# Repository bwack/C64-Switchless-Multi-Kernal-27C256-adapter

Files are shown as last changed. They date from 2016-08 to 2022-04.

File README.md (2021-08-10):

README.txt

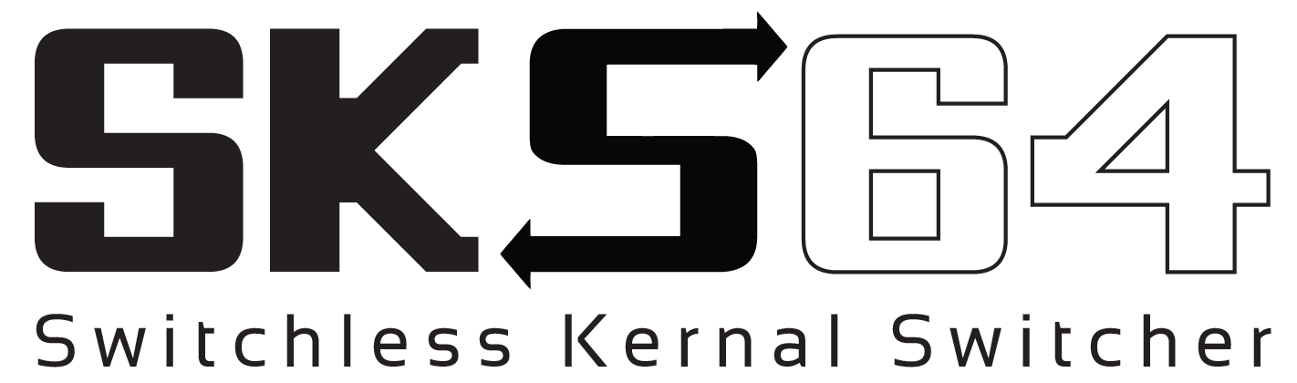
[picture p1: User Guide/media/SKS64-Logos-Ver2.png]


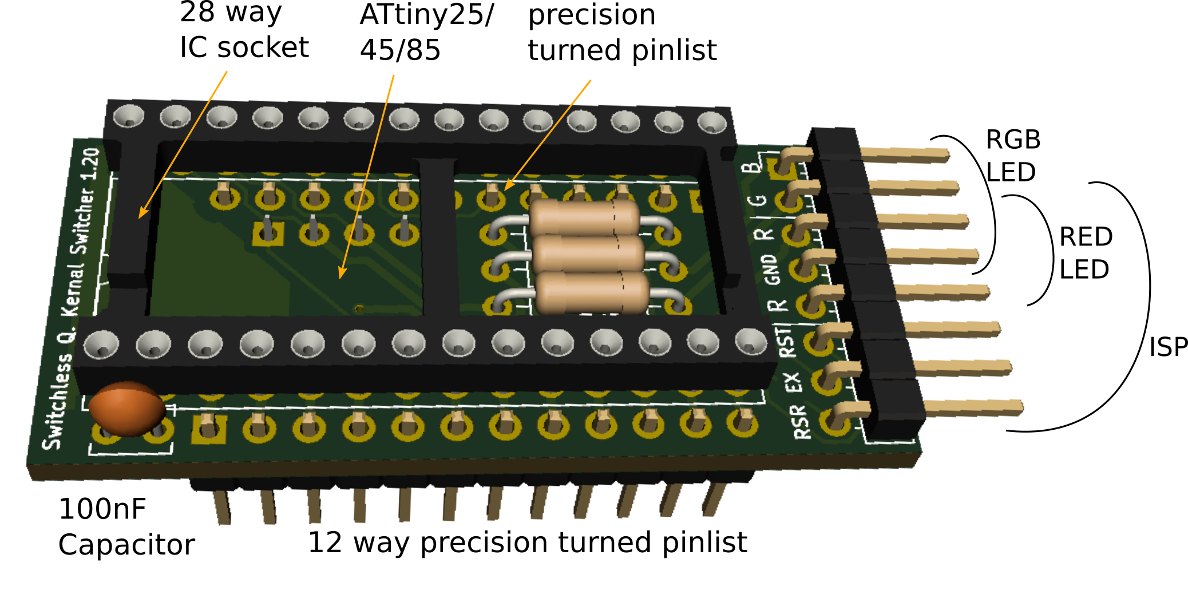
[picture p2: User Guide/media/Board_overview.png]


C64 Switchless Multi Kernel Switch
- 27C256/512 rom adapter for C64's and disk drives.

Designed by BWACK.
CERN OPEN HARDWARE LICENSE v1.2
http://www.ohwr.org/

The CAD files are available on GitHub:
https://github.com/bwack/C64-Switchless-Multi-Kernal-27C256-adapter

All text above must be included in any redistribution

# SKS64 Switchless Kernal Switcher

A kernal ROM adapter and switcher for C64, C64C, 1541, 1541C and 1541-II. The software is written in the Arduino IDE.

# How it works

## Switching Kernals

The current selected Kernal is indicated by a color using the RGB LED as power LED replacement. Holding the RESTORE key for several seconds until the LED flashes. You then release it and tap RESTORE until you get the kernal (color) you want. Wait a couple of seconds and the C64 reset with the new kernal selected.

1541 disk drives:
Now you can have the disk drive and the C64 switch at the same time! The reset pulse issued by the SKS64 now has prepended serial data indicating the bank number. When the SKS64 board in the disk drive is setup in 1541 mode, it will switch to the upper bank when the C64 is switched to bank1 (for example, JiffyDOS).

## Reset

Hold the RESTORE key for two seconds. The LED flashes. Release and wait two seconds for the reset.

## EXROM Reset (optional)

Hold the RESTORE key for five seconds. Some machine language programs change the way computer returns after a reset. In that case the only way to reset to basic is to turn the machine off. By controlling both RESET and EXROM it is possible to "cold start" the machine.

Note: EXROM reset is only available when the ATtiny's RESET pin is disabled (fuse bit #RSTDISBL). This can only be done with HV-programmers (like TL866).

# Hardware

There are two different PCBs for the SKS64.
- "longboard": works with C64 longboards and 1541/1541Late.
- "shortboard": works with C64C shortboards and 1541C/1541-II.

Note: The internals of C64/C64C and 1541/1541C are often mixed up, and you must look inside their cases to be sure which boards they have.

Gerbers and hex-files (for programming) are found under the release-tab above.

# Programming

Programming is done with ISP programmers or High-Voltage programmers. You can use an Arduino Uno as ISP. Please see the User Guide for more information.

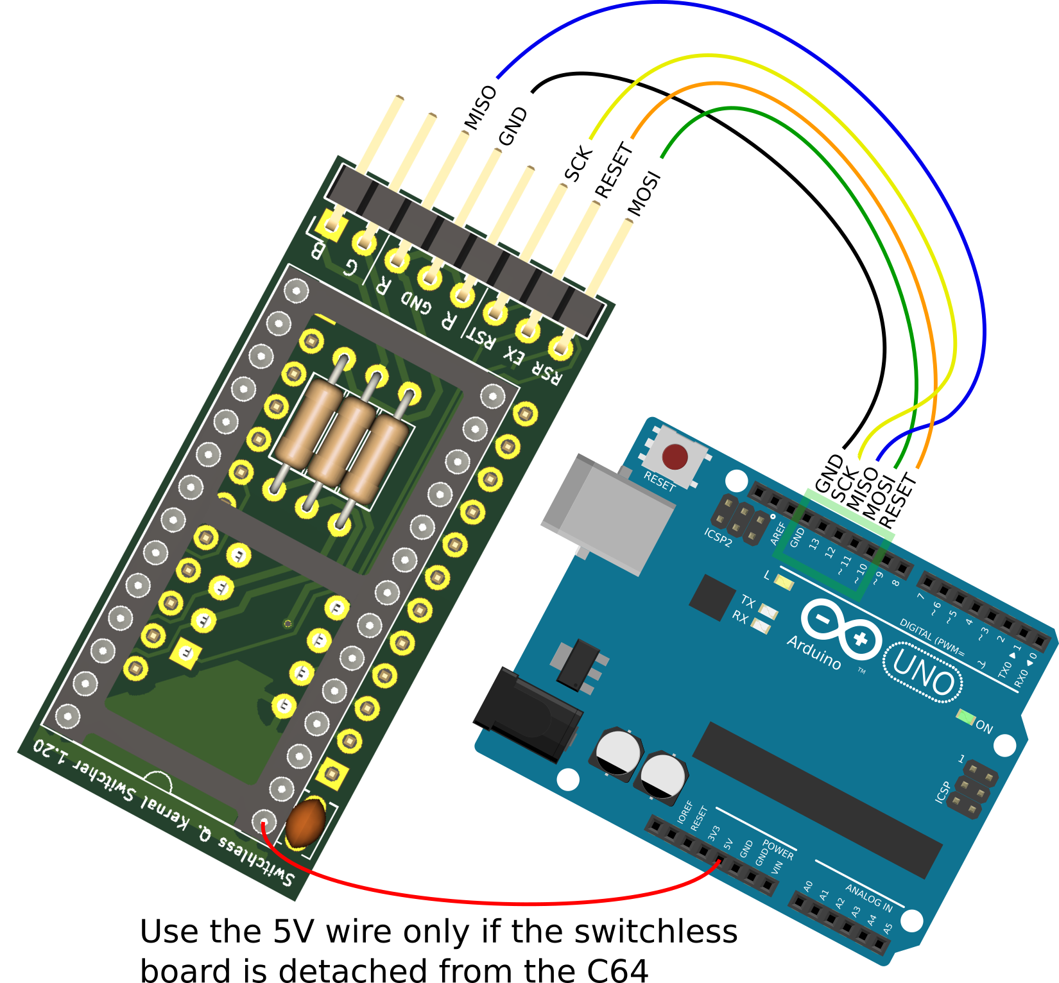
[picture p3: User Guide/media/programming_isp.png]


After programming, the board must enter setup mode. Please refer to the User Guide.

# ROM layout

ROM images are placed in 8k banks.
- C64 Longboard
  - place 4 kernals in a 32k image (27C256).
  - place 8 kernals in a 64k image (W27C512).
- C64 Shortboard
  - place BASIC + 3 kernals in a 32k image (27C256).
  - place BASIC + 7 kernals in a 64k image (W27C512).
- 1541
  - Place CBM DOS + JiffyDOS in a 16k image (27C128)

For 1541C/1541-II ROM images are placed in 16k banks.
- 1541C/1541-II
  - Place KERNAL+CBMDOS + KERNAL+JiffyDOS in a 32k image (27C256)

# Via locations
You can solder 1x1mm pin headers into motherboard vias to wire up RESTORE, RESET and EXROM.

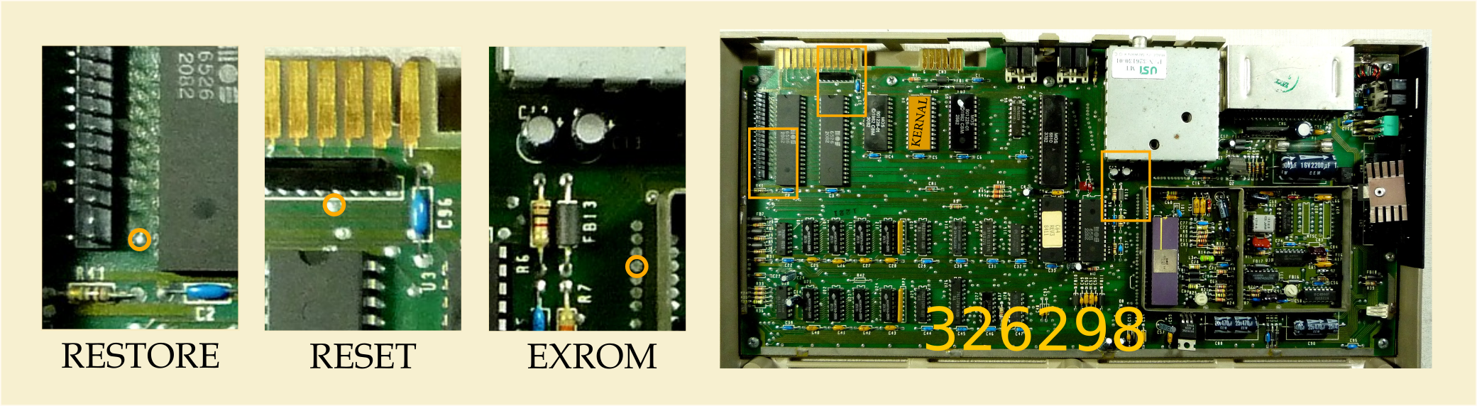
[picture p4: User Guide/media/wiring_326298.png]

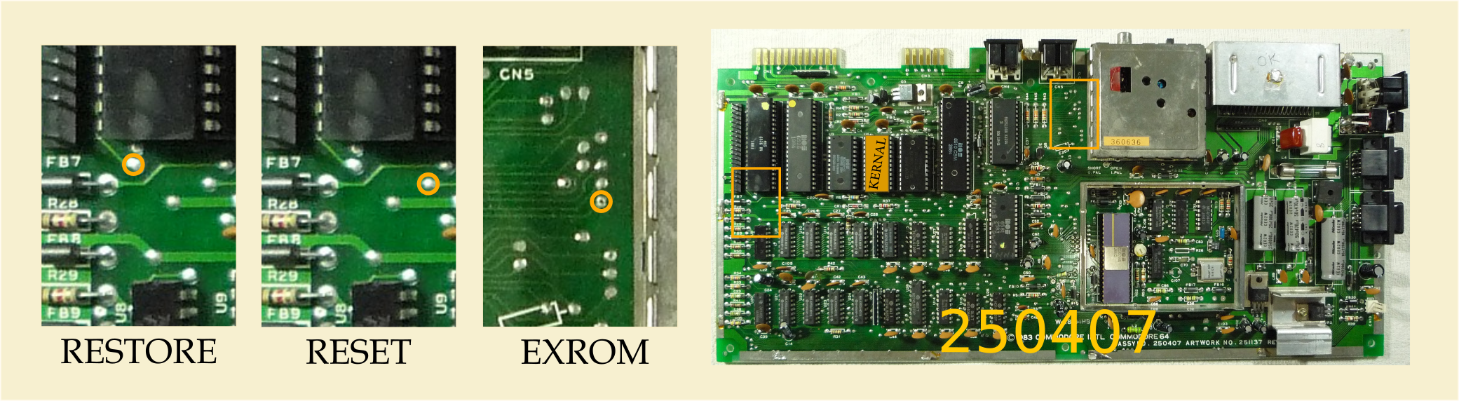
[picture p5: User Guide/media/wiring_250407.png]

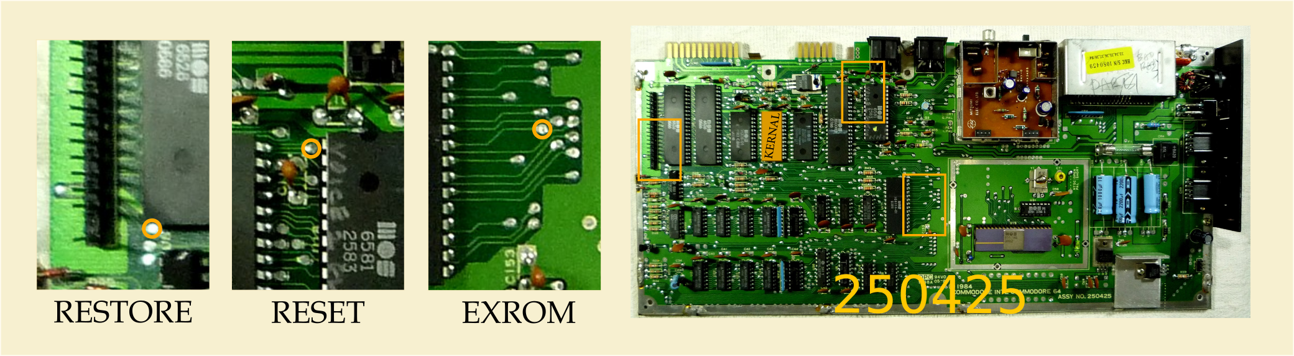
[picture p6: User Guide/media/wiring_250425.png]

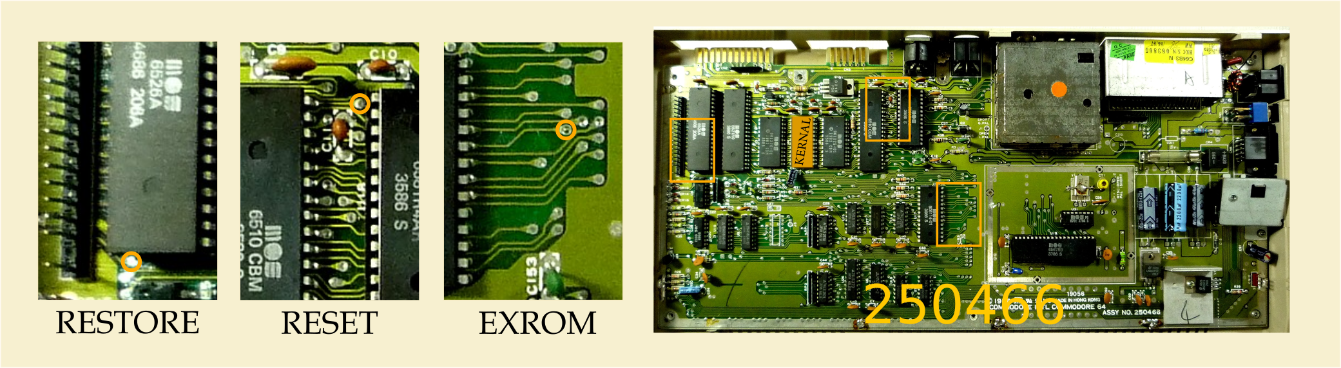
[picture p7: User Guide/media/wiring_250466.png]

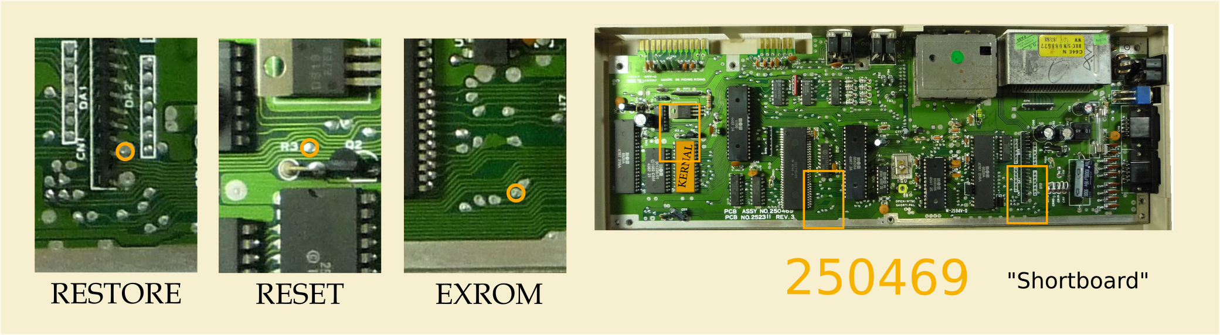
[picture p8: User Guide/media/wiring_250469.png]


# Acknowledgement

The Switchless Kernal Switcher for shortboards is based on Sven Petersen's [C64 Kernal Adaptor Switch shortboard](https://github.com/svenpetersen1965/C64-Kernal-Adaptor-Switch-short-board-). The old shortboard version is located at [DiscoHR's repository](https://github.com/discoHR/C64C-C128-multikernal-adapter). It is possible to use the original LED and cable assembly. This was an idea I found on [tebl's repository](https://github.com/tebl/C64-Kernal-Switcher).

# Project links
- lemon64:  http://www.lemon64.com/forum/viewtopic.php?p=747333
- playlist: https://www.youtube.com/watch?v=oGaI8yLwjh4&list=PLtQOf_JULmrQTB7486X5pXG1Aaxbl_RdE
- OSH Park: https://oshpark.com/profiles/bwack
- Github:   https://github.com/bwack/C64-Switchless-Multi-Kernal-27C256-adapter

# Change log
## longboard version
- Rev 1.21 (2019-07-23):
  - Support 27C512 and 8 banks
- Rev 1.20 (2019-07-14):
  - Eagle -> KiCad.
  - PIC12F629 -> ATTINY45/85. Note: Pinout is different! Don't mix up PIC12F with ATTINY!
  - Programming with Arduino IDE.
  - Programmers: ISP: USBasp or Arduino UNO as ISP. High-Voltage: TL866.
  - Use the original LED or a common cathode RGB LED.
  - User Guide rewritten for this revision.
- Rev 1.13 (2016-09-28):
  - Moved IC2 down to clear space for the socket in the c64.
  - Changes to the silk screen.
- Rev 1.12 (2016-09-18):
  - Increased pad and hole sizes.
  - Removed ground fill from top layer.
  - Added CERN OHL v1.2 License.
- Rev 1.11 (2016-09-10):
  - RGB Led header following RGB led pinout (Blue-Green-GND-Red).
  - Edited silkscreen.
- Rev 1.1  (2016-09-08):
  - sch+brd.
  - Swapped signals #RESTORE and RED_LED. GP3 is input only.

## shortboard version
- Rev 1.0 (2019-07-18)
  - Initial design
- Rev 1.1 (2021-08-10)
  - jumpers for 1541C/1541-II support

Note: The schematic revision follows the board revision number.

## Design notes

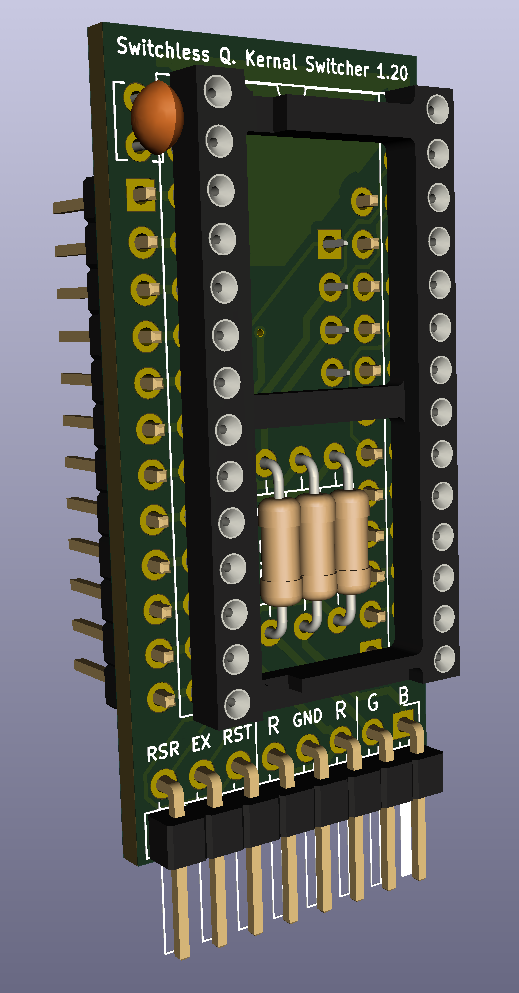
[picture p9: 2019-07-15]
KiCad_longboard/C64_Switchless_3D_front.png

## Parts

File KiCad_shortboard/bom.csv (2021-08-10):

Reference | Quantity | Value | Footprint | Datasheet
C1 | 1 | 100nF | Resistor_SMD:R_0805_2012Metric_Pad1.15x1.40mm_HandSolder | ~
J2 J1 | 2 | 01x14_precision_pinlist | Connector_PinHeader_2.54mm:PinHeader_1x14_P2.54mm_Vertical | ~
J3 | 1 | 27C256/512_28PDIP | Package_DIP:DIP-28_W15.24mm_Socket | ~
J4 | 1 | Wireconnections | Connector_PinHeader_2.54mm:PinHeader_1x08_P2.54mm_Horizontal | ~
R1 | 1 | 1k | Resistor_SMD:R_0805_2012Metric_Pad1.15x1.40mm_HandSolder | ~
R2 | 1 | 3k3 | Resistor_SMD:R_0805_2012Metric_Pad1.15x1.40mm_HandSolder | ~
R3 | 1 | 560 | Resistor_SMD:R_0805_2012Metric_Pad1.15x1.40mm_HandSolder | ~
U1 | 1 | ATtiny85-20PU | Package_DIP:DIP-8_W7.62mm_Socket | http://ww1.microchip.com/downloads/en/DeviceDoc/atmel-2586-avr-8-bit-microcontroller-attiny25-attiny45-attiny85_datasheet.pdf
U2 | 1 | 74LS08 | Note: NOT NEEDED with 1541C version! Package_SO:SOIC-14_3.9x8.7mm_P1.27mm | http://www.ti.com/lit/gpn/sn74LS08

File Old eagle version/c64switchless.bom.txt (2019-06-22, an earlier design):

Partlist exported from C:/Mine Dokumenter/eagle/projects/C64-SwitchlessMultiKernal/c64switchless.sch at 10.09.2016 17:06:57
(edited)

PCB Assembly variant: 

Qty Value            Device          Parts     
1   27C256 ROM       DIL28ROUND      IC1
2   Rounded pin list MA12-1ROUND     SV1, SV2  
1   RGB LED header   MA03-2          SV3       
1   1k               R-EU_0207/10    R1
1   3k3              R-EU_0207/10    R2
1   560R             R-EU_0207/10    R3
1   100n             C-EU025-024X044 C1        
1   PIC12F629P       PIC12F629P      IC2       

Eagle says, What ? :
- IC1:      27C256 ROM = socket for 28 pin IC.
- IC2:      Microcontroller PIC12F629P, 8 pin PDIP
- SV1, SV2: 2x12pin rounded pinlists on the bottom side
            These goes into the C64 socket, and into the
            adapter.
- SV3:      RGB LED assembly header.
            Standard 2x3 male header pinlist 2.56mm pitch
- R1,R2,R3: Resistors. Controls the brightness of the RGB LEDs.
- C1:       100nF ceramic capacitor, 2.56mm pitch

RGB LED assembly:
Qty    Value       
1      5mm RGB LED Common Cathode
300mm  4 wire rainbow IDC cable
1      2x3 IDC connector
80mm   heat shrink tubing 3.2mm/1.6mm 2:1 thin wall black

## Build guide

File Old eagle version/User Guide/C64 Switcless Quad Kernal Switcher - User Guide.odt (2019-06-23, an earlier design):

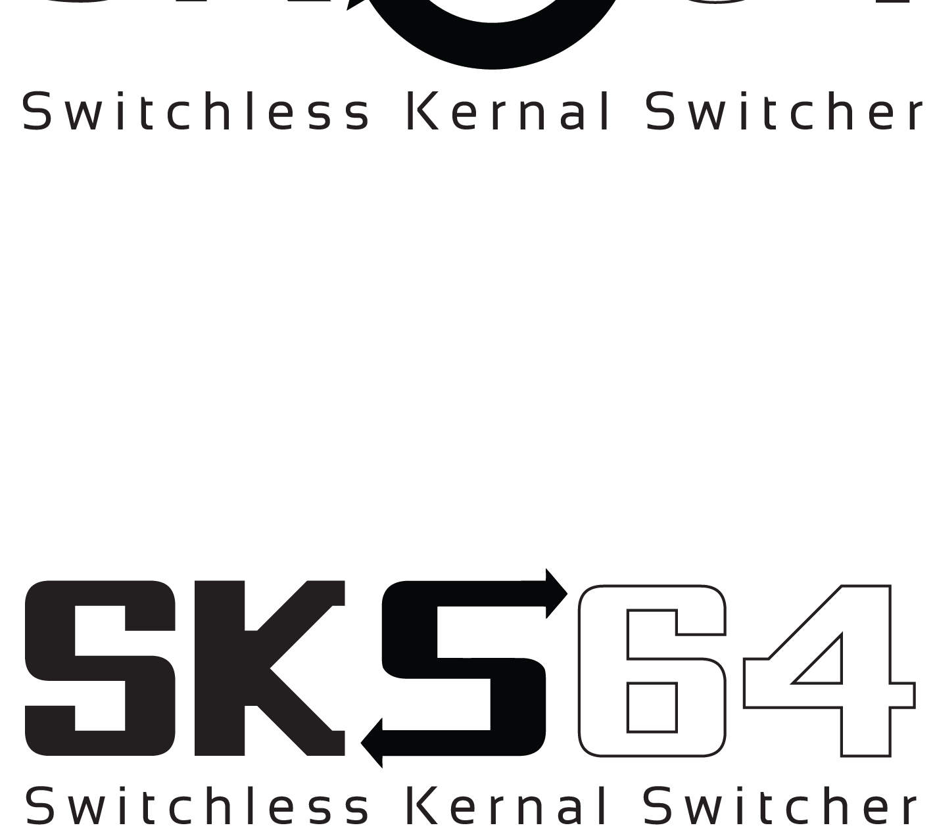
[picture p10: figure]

a Switchless Quad Kernal Switcher design for the C64 and C64C

User Guide

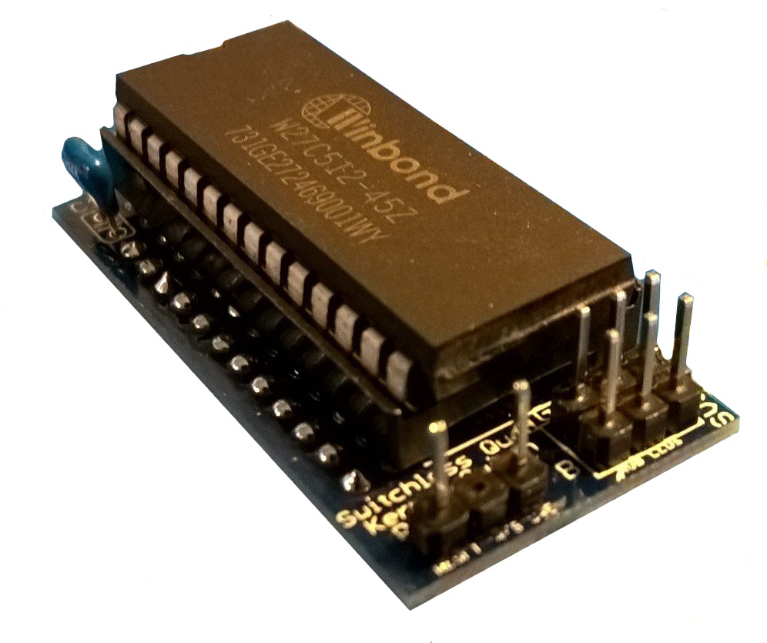
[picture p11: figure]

# Introduction

The Switchless Quad Kernal Switcher turns your C64 into a flying raspberry flavoured pumpkin that can boost the performance of your computer. It is high on itself and makes your C64 smoke out of the I/O ports. It is UL94 rated, so no flames though. Wear eye protection. Selected Kernal is indicated with a color power indicator. Maybe you just need a 24-28 adapter, the Switchless Quad Kernal Switcher is just what you need.

There is also a C64C version, for people who are fortunate to have 250469 PCB boards. Note that some C64C looking cases may have C64 motherboards ! You have to open it up to see.

The SKS64 can also be used as a 24 to 28 pin adapter. Only sockets and the ROM is required for the adapter.

# Board overview

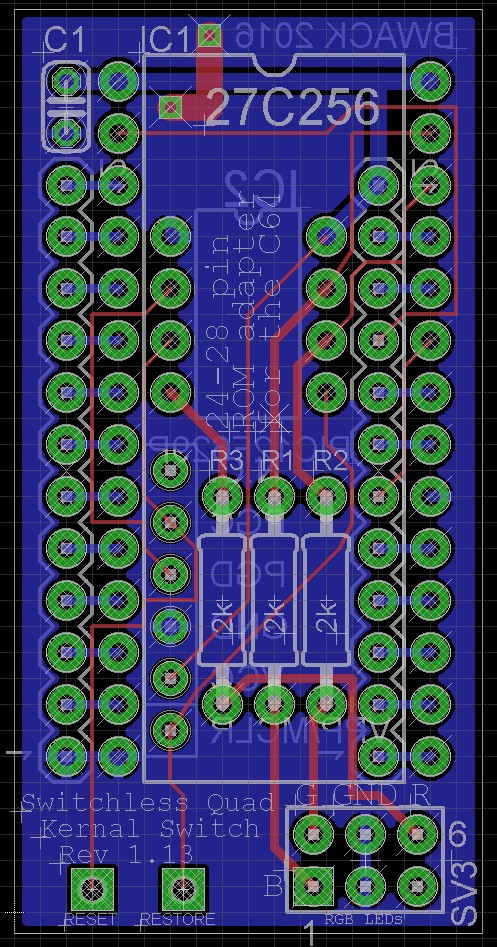
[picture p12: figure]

100nF decoupling capacitor

IC Socket for the EPROM

Note: Cut the surrounding solder joints flush with the pcb to get the IC socket to sit flush on the board.

Two 12 pin - pin headers

(bottom side)

IC Socket for the PIC MCU (bottom side)

ICSP Programming header

LED resistors. You might want to try a higher resistacnce on R2 because green tend to be quite bright and swomp out the other colors.

# Switching Kernals

The selection mode is entered by holding RESTORE for 3 seconds, and is indicated with a slight flash of RED on the RGB LED. Be quick and continue to tap RESTORE until the desired color on the LED is shown. The computer reset after two seconds of no activity.

# RESTORE as reset key

Hold the RESTORE key for 3 seconds then release. Wait two seconds for the reset.

# Board Assembly

Because the board is so convoluted, the components need to be soldered in a special order to be able to reach all the solder pads. Using an IC socket for the ROM instead of precision turned socket rows is possible though time consuming, because you have to cut the solder pins flush that lay under the socket's footprint.

Here you see the board from the underside. I have inserted the IC socket that is later soldered into the C64 motherboard (longboard). 1. Start with the first 12-pin row on the left bottom side. 2. 8pin PDIP socket bottom side, 3. 28pin IC socket top-side. 4. Solder the last 12-pin row on the right bottom side. Tip! When soldering the last row of pins, attach the motherboard-ic-socket (24pin) as shown in the image to align the last row of pins before soldering (no. 4).

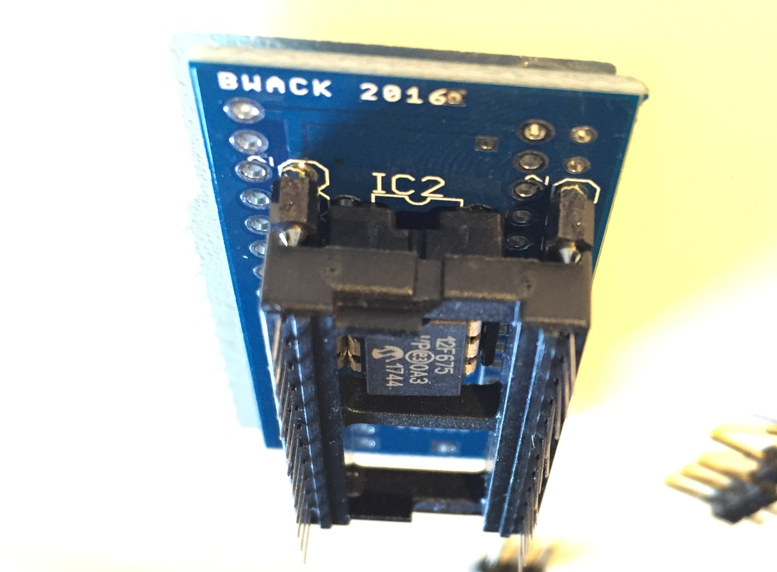
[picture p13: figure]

1

Soldering order numbers:

2

3

4

# Installation

- Locations of the INTRES and RESTORE signals
- show images of different C64 motherboards and bubble-zoom closeups of where to attach intres and restore

TBD

# The RGB LED Cable Assembly

The current selected kernal rom image is indicated with an RGB LED. RED, GREEN, BLUE and CYAN. It must ba a common cathode type*. Use the LED pinout diagram as shown below to locate the negative, red green and blue LED connections. Attach wires and use heathshrink tubing. You can see an excellent realization of this in the pictures below done by @ (https://twitter.com/thilographie_de)thilographie_de (https://twitter.com/thilographie_de) . Thank you for letting me use your pictures.

The other end of the cable goes into a 2x3 female pin header. The connections for R, G and B in the pcb are noted on the silk-screen (the white text on the pcb). You can solder the wires directly onto the pcb if you like, but it is nice to be able to separate top enclosure where RGB LED is clipped into from the rest of the computer.

* A common cathode means that all cathodes are joined together. The cathode is the "negative" side of the LED. I bought it on ebay, and the product title was: "4PIN 5mm RGB LED - Tri-Colour 3 in 1 - Frosted Diffused Common Cathode".

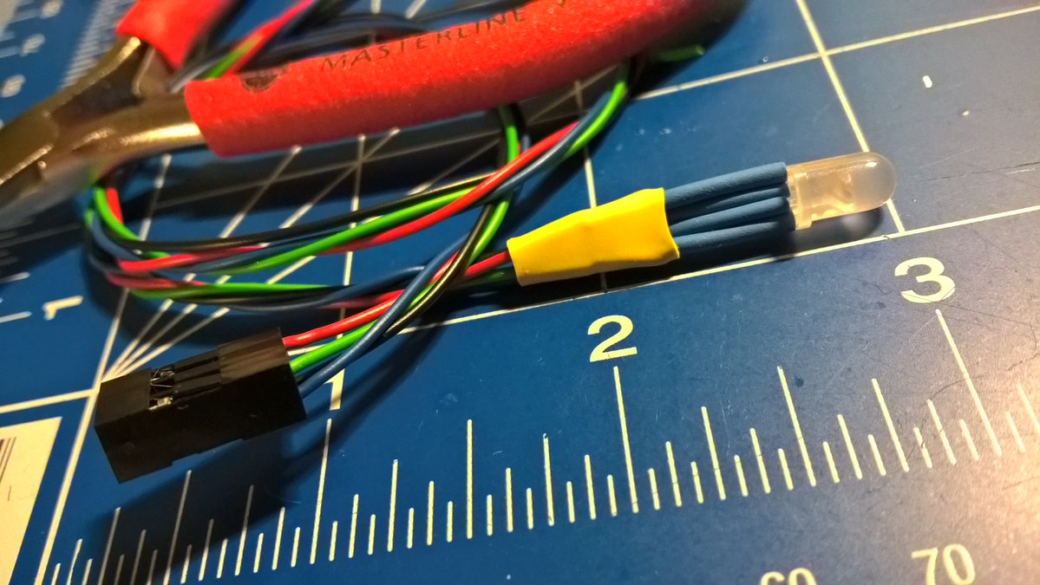
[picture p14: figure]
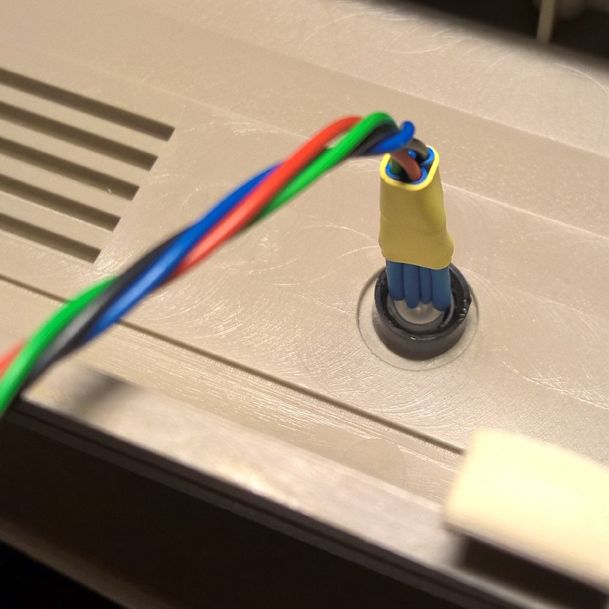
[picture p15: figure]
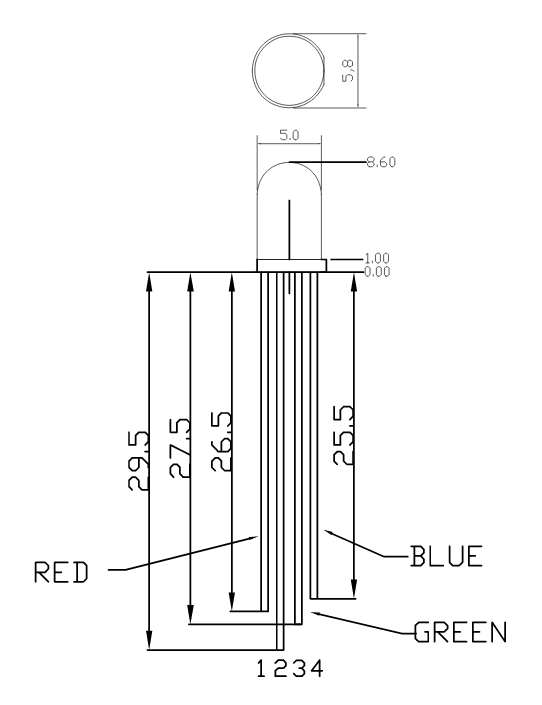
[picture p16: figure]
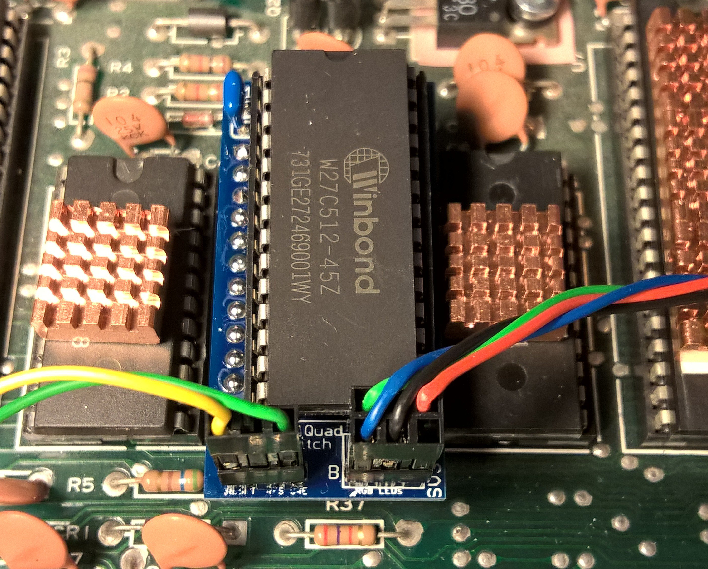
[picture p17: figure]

# Programming the PIC microcontroller

Programming the MCU is done by loading the .hex file into your favorite PIC programmer software. The MiniPro TL866 Universal Programmer is my favorite. Clone or download the whole project to your computer first*. Locate the .hex file. There is one for PIC12F629 and one for PIC12F675. Insert the PIC onto the programmer. Then start the programming process.

- Note that it is safest to download the whole git project first and then locate the hex file from there. It has come to my attention that people have attempted to fetch only the .hex file directly of the github repository. What happens when you right click and save-as in your browser is that you actually are getting a HTML file and not the .hex file.

# Alternative Firmware and single LED version

For use with existing LED, checkout tebl's github repository. His kernal switcher is based on this design and has a different firmware behaviour that suits a single LED better.

https://github.com/tebl/C64-Kernal-Switcher

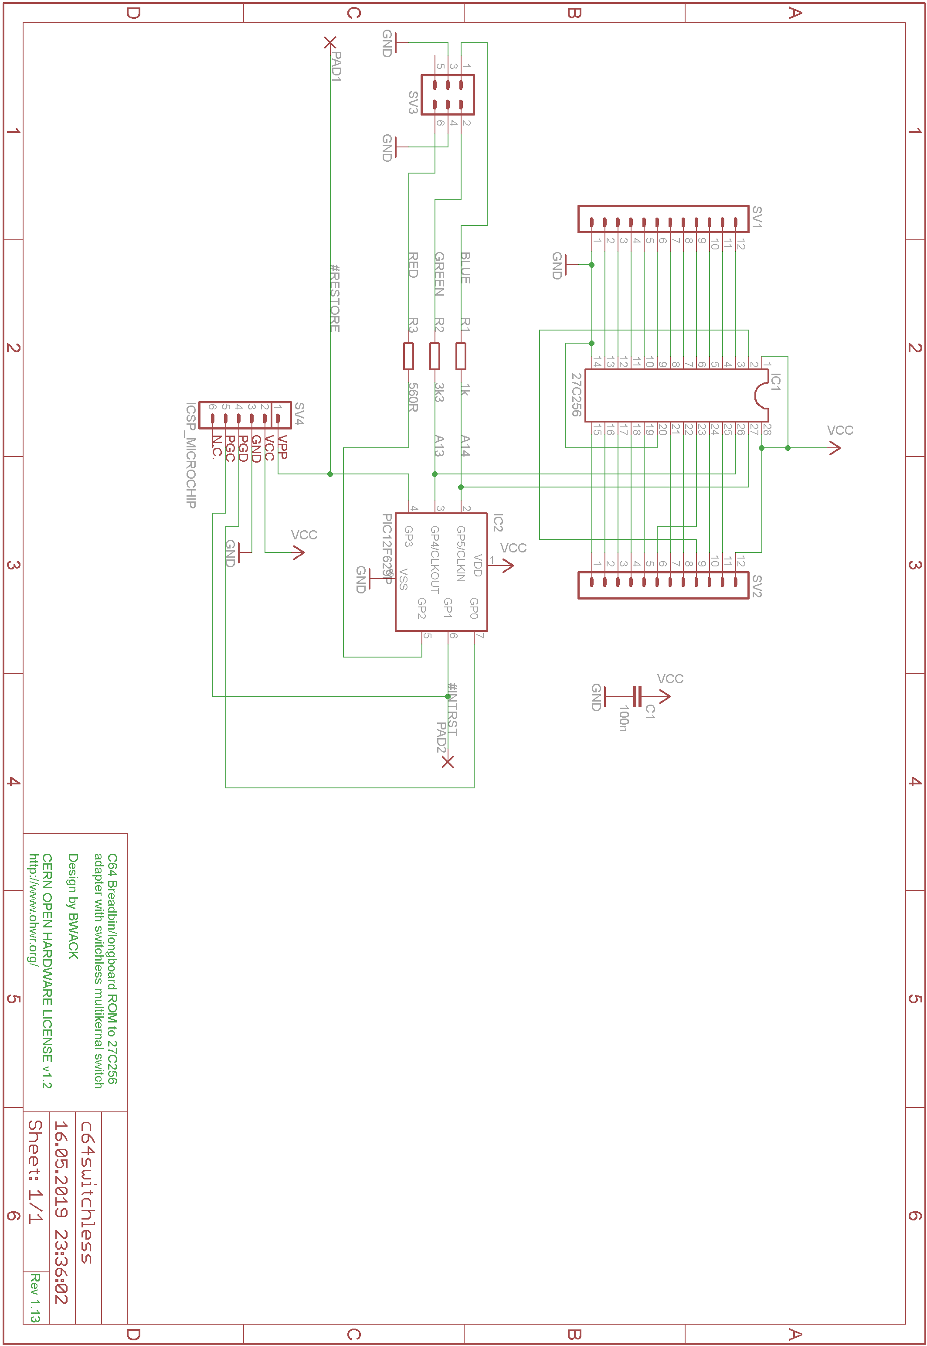
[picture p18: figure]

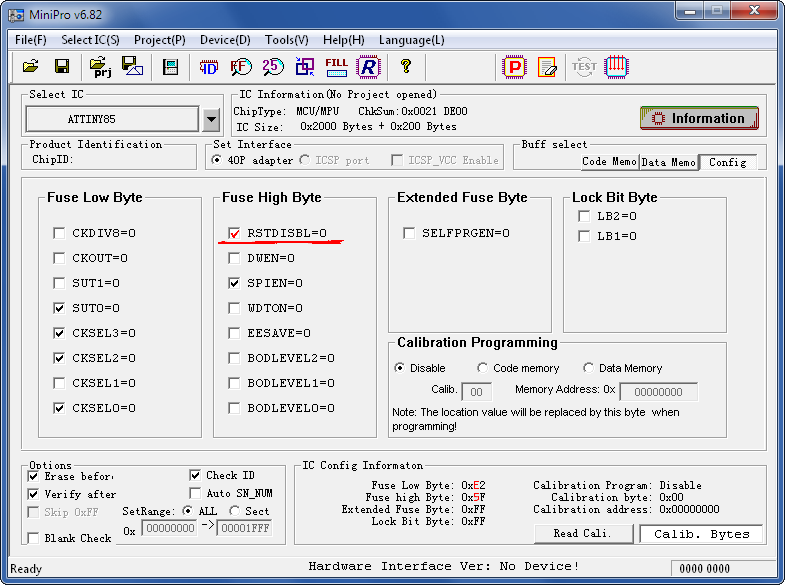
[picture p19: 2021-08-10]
User Guide/media/minipro_checked.png

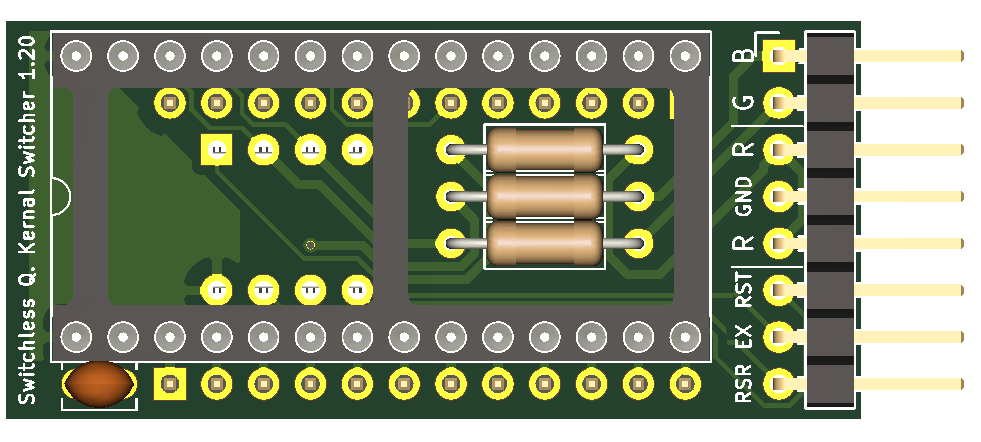
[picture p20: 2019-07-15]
User Guide/media/sks64_sideways_prlx.png

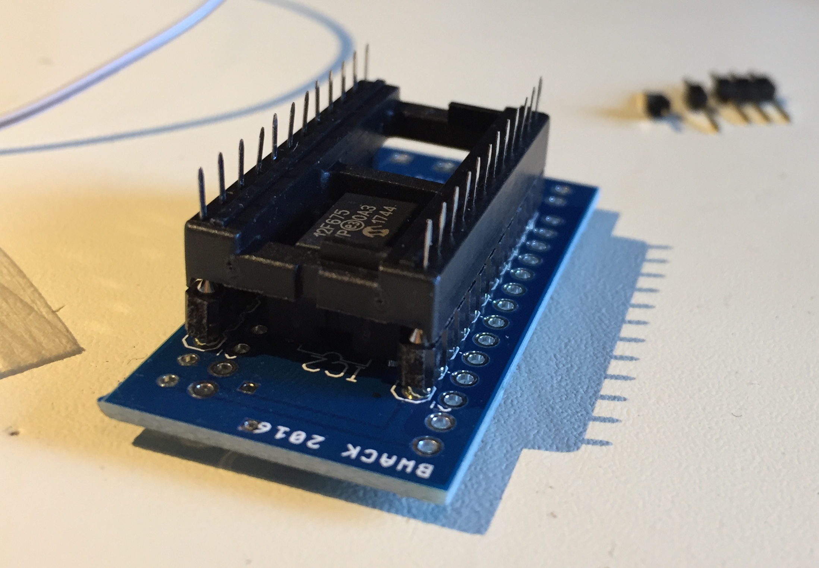
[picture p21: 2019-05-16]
User Guide/media/IMG_0099_SKS64_1_13_underside on socket.jpg

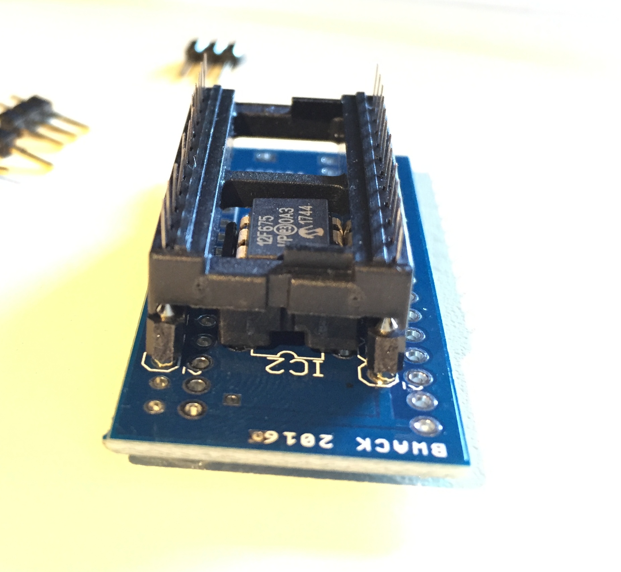
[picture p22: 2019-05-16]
User Guide/media/IMG_0100_SKS64_1_13_underside.jpg

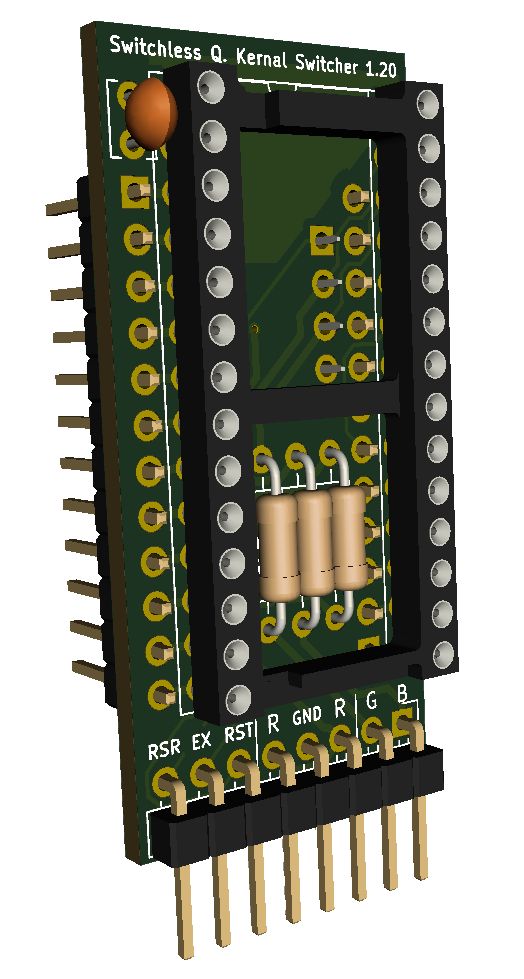
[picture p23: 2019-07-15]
User Guide/media/sks64_v1_20_3d_whitebackground.png

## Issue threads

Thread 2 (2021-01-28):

Black screen at power on with C64C shortboard

kavanozz, 2021-01-28:
I built the shortboard for my C64C with EXROM enabled via TL866ii, programmed and installed 27C512 and configured at power on for my configuration (4th option). Kernal switching works by pressing Restore key for 2 seconds and Exrom reset works with 5 seconds pressing. But when I turn off the machine using power switch and turn on, I get black screen. If I press Restore key for 5 seconds the machine resets and boots properly and everything normal until I turn it off again. I repeated this many times and never could get the machine boot directly.

gh0stless, 2021-01-28:
I had problems with the shortboard in a C64-C. It didn't do a cold start. I changed lines 317, 334 and 343 the delay () value from 300 to 400, now it works.

kavanozz, 2021-02-04:
Thanks for the suggestion. I tried 400, then 600 but didn't fix my problem. I also tried with another Attiny85. Then something happened and my switcher stopped working completely. I will build another one and try again.

bwack, 2021-02-05:
I'd like to have a look at this problem soon. Is the cold start (quickly off then back on) causing the reset line generated by the 555 just too short ?
Suggestion, if you'd like to experiment:
in:
https://github.com/bwack/C64-Switchless-Multi-Kernal-27C256-adapter/blob/a58f48c7adf1041987e753e416d5cc985b262627/SKS64_SKETCH/SKS64_SKETCH.ino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
Try changing next_state from STATE_IDLE to STATE_RESET. Then it should perform a reset on cold start.

1. Is your attiny85 from a trusted source? ebay/aliexpress bought IC's are almost all fakes.
2. Are your fuses set to: highbyte 0x62, lowbyte: 0x5f ?
3. are you using any cartridge device that also controls the reset line?

kavanozz, 2021-02-05:
It didn't matter whether a quick turn off/on or a long one. I will try code change once I build the new board.
1. All ICs from Mouser.com. I have 10 x Attiny85's. I have tried with 3 of them with the same results so far.
2. Yes
3. No, but I have C64 Lumafix installed. I didn't think to remove it when I was testing. I will try removing it with the new board before testing the code change.
BTW, I had tried a 27C256 with proper initialization (short-short led) and had the same results.

kavanozz, 2021-02-05:
I rebuilt a second board. Original code works with the same issue, but modified code doesn't work at all. Even reset with Restore key doesn't help. I can select the board/eprom type, or change the kernal bank. I can see it working via led responses but computer never boots. Also tested removing Lumafix which didn't make any difference.

I keep changing Attiny's and after a few swaps nothing works. I erase and reprogram and it sometimes helps. I used a total of 5 of them so far. Here is a question. Is it possible that if the board/eprom type is modified, the eprom selection resets to the first bank? I don't think this is the case because even after replacing Attiny and configuring it, I see it boots with 3rd or 4th kernal.

If I remove disable_reset control and reprogram using Arduino, is it Ok just to set the disable_reset bit using TL866ii, without rewriting flash and other portions?

bwack, 2021-02-06:
I'm sorry you have trouble. I don't have the time to look at it now, but I will be glad for anything you find.

1. The ATtiny's of yours are probably just fine. No need to swap them.
3. Lumafix works fine with the switcher.
I followed Sven's 250469 kernal/basic adapter, the nand-chip trick with having basic in bank0 and kernals in banks 1,2,... I haven't tested the C64C version.  Can you check Sven Petersen's trouble shoot here ? https://github.com/svenpetersen1965/C64-Keyboard-Controlled-Kernal-Switch/blob/master/Rev.%201/pdf/C64_Keyb_KSw_v1.pdf .. Pay close attention to contact continuity. Ensure that there is continuity from the socket to the motherboard, even better check from socket and over to the cpu to be sure there is no broken traces.

Regarding the question about eprom selection. I don't understand, sorry. Can you help me understand ? :) I have a suggestion though. You can remove the attiny and try fixing the address pins to say bank1. This should rule out the microcontroller. If the address lines are hardwired, and it still doesn't work then there must be something else wrong.
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
At the ATtiny (I presume it is socketed) pulled out. Ground MCU_A14 and MCU_A15, and put 5V on MCU_A13. This should select bank1. (Ps. Selecting bank0 (basic) is "illegal" and is not supposed to work.)

Yes you can write the fuse bits without rewriting the code memory using the tl866ii

bwack, 2021-02-06:
Oh shoot, regarding the code changes. I see now that if the change is put in STATE_SETUP, then the reset will never be reached on a normal boot (not holding restore at boot). What i wanted to try was to reset the machine at power on. To do that you could try adding.

      pinMode(INTRST, OUTPUT);
      delay(300);
      pinMode(INTRST, INPUT);

at the beginning of loop()

StormTrooper, 2021-02-07:
I was having a different issue (also shortboard with 27C512) where the C64 didn't reset after selecting the ROM.
You could select the ROM and then had to power off/on and then it booted correctly.

I've now added the above code and its fixed it issue.  C64 resets correctly after selecting ROM

kavanozz, 2021-02-08:
I didn't have much time but worked on this a bit tonight. Here is my findings:
1. Adding the lines to the end of setup() also did not fix it for me (assuming I had to revert back the first change you suggested on "case STATE_SETUP").
2. I enable EXROM RESET functionality (0x62, 0x5F), I cannot do cold boot.
3. If I disable EXROM RESET functionality (0x62, 0xDF) with the original code, I cannot enter setup to select board/eprom type, **but it boots fine and I can change the kernal**. Since the default is longboard and 4 banks, it functions like that.

At the end, I changed the code to make shortboard/8 banks default and I can use it now.
  banks = EEPROM.read(BANKS_EEPROM_ADDRESS);
  if (banks==255) banks=8;
  shortboard = EEPROM.read(SHORTBOARD_EEPROM_ADDRESS);
  if(shortboard==255) shortboard=1;

I also have breadbin C64 with longboard 250407. I will build the SKS64 for it when I get a chance. Thanks for creating and supporting this device.

bwack, 2021-02-14:
Thanks ! That is an interesting find!
This suggest a couple of things I'd like to test. Especially 2. and 3. What is different with EXROM reset, and why does the machine need a reset from the attiny. Maybe the shortboards have really short poweron reset. Also I'd like to check why the attiny does not go into setup mode if EXROM reset is disabled (attiny reset pin enabled).

I will order parts and build the shortboard version and test it myself on my C64G. It has a 250469 board.
I wonder if I should make  a avrgcc project of the code and have a makefile produce all the variants (longboard,shortboard,romsize) automatically when executing make., but first I'd like to find the root cause.

kavanozz, 2021-02-15:
I built the longboard version and installed on my breadbin with 250407 rev A. Installed the original sketch code and used a 27C256 this time.  Disabled Attiny reset pin to enable EXROM. This one also doesn't go to setup mode, but default config is the right one.
I removed Attiny, read it's config on TL866ii and confirmed the reset pin was disabled (0x62, 0x5F). I didn't have time to try another one, but I am now suspecting that these Attiny85's are peculiar, even though they come from a very trusted source. I will order different model (45 or 25 maybe) or from different source and try again when I have a chance.

I also installed RGB led with this one and it's beautiful. I decided to buy one for 64C. I found this item on Ebay. I think it should work.
https://www.ebay.com/itm/100pcs-2x5x7mm-4pin-Common-Cathode-Diffused-RGB-Tri-Color-Rectangular-LED-Diodes/121751750432

kavanozz, 2021-03-02:
Bwack, I finally got a bunch of Attiny85 and 45 from Jameco. But the behavior didn't change (even with suggested code changes from you and others).

One thing I need to correct is that, when I disable EXROM functionality, I can still enter setup mode. In my initial testing, my C64 machines were never booting when I entered setup mode. When I disabled EXROM function, C64 boots right away with whatever kernal config is present. That threw me off thinking it was not going into setup mode. But I realized, if I just kept holding Restore key, it was indeed going to setup mode. Now I can just use default code without modification. So part of my previous feedback was wrong. I updated that.

In summary, I cannot use the machines when I enable EXROM function by disabling Attiny reset pin.

bwack, 2021-05-02:
Hi Kavanozz. I have finally built one and installed it in my C64G with 250469 motherboard.
One thing I found is that I have same issue as you. I need a warm start after the cold start. I haven't tried disconnecting exrom yet.
Another thing I noticed was when I tried an EPROM (the ones with window) it was more stable than the EEPROM I have. Though problems with the EPROM too. I will hook up the scope and have a look. I'm suspecting a couple of things.
- the attiny doesn't boot fast enough compared to the longboard. Maybe this is a thing when you hardcoded the shortboard-7kernals mode and removing the call to eprom. Calling eprom probably takes some time..
- There is an and gate here.. It adds a propagation delay to the already delayed BASIC/EXROM signal from the PLA. Maybe in sum it is too much delay ?
I'll hook up my digital discovery logic analyzer and have a look at the timing soon.

Hans

bwack, 2021-05-03:
Good news.
While making a video I noticed that the LED was flashing to indicate EXROM_RESET mode.
Removing that delay at the beginning of the program helped the computer to warm start. I haven't digged any deeper, but flashing the led means changing A13..A15, and if the C64C has a shorter reset time than the C64 longboard, then it can be a problem :)
Here is the new firmware.
https://github.com/bwack/C64-Switchless-Multi-Kernal-27C256-adapter/releases/tag/fw1.3

kavanozz, 2021-05-26:
Hi bwack, thanks for the update and the fix. It's working for me without any issues now. Closing this issue. Great job!

Closed 2021-05-26.

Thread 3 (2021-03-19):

Calrification on documentation (or bug?)

glbyers, 2021-03-19:
Hi,

Thanks for the project! I just wanterd to clarify something in the documentation regarding programming in HV programmer wrt reset disabled;

"Make sure that Fuse Low Byte, high byte are 0x62 and 0xDF if reset is enabled, or 0x62 and 0x5F if disabled."

I _think_ this statement is inverted (double negative). If I tick "RSTDISBL=0", I assume we're saying "enable reset", in which case high byte will be 0x5F. If we leave "RSTDISBL=0" unticked, this would be "disable reset". Is that right? Thanks!

glbyers, 2021-03-20:
I looked at the doco for the attiny and I guess this is why you made the point to say high byte should be 0x5f if disabled. I think the TL866-II interface is confusing. I'll close this one. Thanks!

bwack, 2021-03-21:
Thanks! You were right about why I only mention the hex values. The tools are many and it can get confusing very fast.

Closed 2021-03-20.

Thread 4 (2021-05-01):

No power led when Eprom set in 27C512 (shortboard)

lolof70, 2021-05-01:
Hello,

All is working but when using (short board version) with a 27C512 (windbond) in 27C512 mod, the power led is not on.
It just light on when switching kernel or in setting mode.

Using the same 27C512 but with setting as 27C256 (in setting mode), I just have 3 kernel but power led is working as it should...  What could I try to get the led power on on 512 mode ?

Thank you.

darylrichards, 2021-05-01:
No, the same pin for A15 on the ROM is used for the LED. It can't be both.

lolof70, 2021-05-01:
Thanks, I did not knew. Then, I will switch to 256 Mod.
Thanks a lot for this very nice switcher

lolof70, 2021-05-01:
After some try, I have massiv problems....
If using alone without cartridge it's switching well between the kernel.
But if it's in use with cartridge like EF3, KFF or with a sidekick64, this does not work as it should I think.
When killing the EF3 or KFF, it does not return to the basic, black screen with lot of corruption most of the times...
When using with Sidekick64, when returning in Menu I can see for a short time that before to go into the sidekick64 menu it calls a kernel that is not the active one then freeze, seems it always calls the last kernel from the eprom, in this case Evox....
I tried in 512 as 256 mode, when 256 with 512 eprom I doubled the content of the eprom...
I did the bin file in this order :
64c.251913-01 + Jiffy + Evox...  (33k) I doubled it to fill the 27C512. I then try with the setting for short board 256 eprom and also short board 512 eprom... Results is the same.

I did correctly filled the Eprom ?
What could I try to get the sks64 working nicely with those cartridges.

Thanks again for the help.

bwack, 2021-05-02:
Did you try to go to basic with the menu button on the KFF? I tested it with my long board version. If already in basic and switching kernals machine returned to basic. But with the KFF in menu mode, it crashes when kernal switching.. Then I can click menu and I get back to menu.

The sks64 is dead simple. To the C64 it issues a reset and provides ROM set to a bank. Thats it. How can I fix this I dont know.

Have you tried disconnecting exrom from the sks64 ?

lolof70, 2021-05-02:
Thanks for the reply.
With Exrom line connected, when going to Basic from KFF (F7) = crash.
Just tried with Exrom line disconnected, a quick test show that it solves the issues I have.
With sidekick64 is starting (when calling its menu), it  does not show anymore another kernel than the one active from sks64.
Same with KFF, no crash when going to basic, switching kernel....

The fuse are set like this with my TL866 : Low Byte 0x62 and high Byte 0xDF. I just read that using Exrom, reset should be not active and for that High Byte should be 0X5F.

Is it correct ? Can it be the mistake ?

bwack, 2021-05-02:
Hi. I'm working on this now and soldering up a board. It is not a mistake. In the user guide i say that for reset disable you need 0x5F. I think maybe the confusion that many has is that it says #DISBLRST=0.. Theres like three negations there so it looks confusing. A checkmark in minipro means that the bit is 0, and it is active zero. so to get DISBLRST feature you need a check mark there (0x5F). :)

lolof70, 2021-05-02:
Then I did this mistake... I have to set it 0X5F for Exrom....
Yes, mistake is from me, not from user guide... When I told "can it be the mistake ?", I meant with this "my mistake" to have set the fuse to 0x62...

I will try with 0x5F and will tell you if it's working fine.

Thanks

lolof70, 2021-05-02:
With Exrom connected and with the fuse set to 0x5F, it's working stable from my first test.
I have the same as you with my KFF. Changing kernel in KFF is working but I have to do a reset after. It's probably due to the way the KFF is working. I still have to experiment deeper. But this solved also issues I had with sidekick64...
Perfect ! :-)

darylrichards, 2021-05-02:
Just to ask - are you running the version with the EXROM init patch I submitted? Otherwise EXROM is held high instead of floating...

lolof70, 2021-05-02:
After some more test.... Not stable. It's almost the same. It works once than after power off on, almost same as before :-(
I am using the hex version 1.1 from 25 July.

bwack, 2021-05-02:
Thanks Daryl. I'll update the hex files on the releases file.

bwack, 2021-05-02:
New release.
Going to test this now.
https://github.com/bwack/C64-Switchless-Multi-Kernal-27C256-adapter/releases/tag/FW_1.1

lolof70, 2021-05-02:
Did some test with 1.2

With expander KFF active, I can go to basic then switch to jiffydos for exemple than the C64 freeze till I push the KFF bouton menu. From there I can quit and go to Jiffydos. From Sidekick64/EF3, impossible to quit to basic. It freezes the C64

Thought , I am not sure I am doing all right...

bwack, 2021-05-02:
I tried the new firmware myself today. I experience problems too with cold boot. I also noticed that it was almost impossible with a winbond EEPROM (reprogramable/without window), and it worked better with aother EPROM (an eprom that has window). Will have to crack out the logic analyzer soon :)

bwack, 2021-05-03:
Good news.
While making a video I noticed that the LED was flashing to indicate EXROM_RESET mode.
Removing that delay at the beginning of the program helped the computer to warm start. I haven't digged any deeper, but flashing the led means changing A13..A15, and if the C64C has a shorter reset time than the C64 longboard, then it can be a problem :)
Here is the new firmware.
https://github.com/bwack/C64-Switchless-Multi-Kernal-27C256-adapter/releases/tag/fw1.3

bwack, 2021-05-03:
While it got better, sometimes i need to powercycle the machine to get to the KFF menu. I don't know how to fix that.

lolof70, 2021-05-03:
Just tried new firmware on long and short motherboard.

I did quick tests with cartridges alone. No expander....

Short board :

-Without cartridges, it seems to work well, I just had one time a problem by switching kernel...

- KFF, that's better now, the C64 start and I can select kernels. Just the same as before, if I switch kernel, I have to go again in KFF menu and F8 to quit to basic with new kernel. Switching from Basic freeze the screen till I go again in KFF with menu button. With exos V3 Kernel, it does not work.... Normal kernel, jiffy ok.

- Sidekick64 start and go directly in Sidekick menu as it should. When quitting to basic after to have started a game, it freeze. I can go back in sidekick menu and work with the sidekick but I never can go back to basic. I have to power the c64 few seconds, start in sidekick menu and quit to basic (without starting anything before to quit).

- EF3, That's the cartridge who is working the best. Nothing special...

All of those test were done quickly.... Maybe there will be other things...

On lang board, it' almost the same problems as on the short one.

Thank you for all the work on this. I can imagine this is a nightmare with the timing with all those expansions cartridges....

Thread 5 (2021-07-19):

Longboard 8 Kernal doesn't set A15 high after cold boot

Neukam, 2021-07-19:
I'm using the SKS in a 1541 with the A14 and A15 address lines tied to the drive's device ID inputs so that I can switch between JiffyDOS and stock as well as setting the device ID.  I'm using SKS64_SKETCH_V1_3_attiny85_RGB_LED.hex firmware set in Longboard 8 kernal mode.  If I power cycle the drive with kernal 4-7 selected, the SKS will not set A15 high at power on.  A13 and A14 will return to their previous state as they should, but A15 will always be low.

bwack, 2021-07-26:
How do you control the attiny ? The attiny relies on a momentary switch (the restore key) as input.

bwack, 2021-07-26:
I'm looking through the code for possible issues.. I just wonder if its got to do with the fact that the same led was originally used for blinking the red LED.

Neukam, 2021-07-26:
I installed a small tactile switch in the front of the case with hot glue and connected it to the restore input and ground.  It works great except that if A15 is high when I turn it off, it will always be low when I turn the power back on.  The same behavior can be seen on my C64 if I set it to 8 kernal mode, but I normally have that in 4 kernal mode so it isn't a problem for me.
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

bwack, 2021-07-26:
The mod looks perfect!
I'm finding some uninitialized variables that may cause this. I've seen this problem now and then without knowing why, then it would just seem to work.
I wonder, does the drive have a connection with the reset line of the c64 ? I wonder if I could make some crude communication over the reset line. When the SKS64 in the c64 holds the reset, the SKS in the 1541 could listen for a message on the reset line such that the C64 and 1541 has the same rom number.

Neukam, 2021-07-26:
The drive does not reset if I hit a reset button on a user port or cartridge port device.  It does reset when the C64 is power cycled and if I send @I in JiffyDOS.    I'm looking at the schematics now to see if it would be possible.  It would be an interesting project.  It might be useful to set the state of A13 to select JiffyDOS or stock depending on which rom is selected on the C64 with the SKS sketch programed to know which of the available ROMs need JiffyDOS.  I'm more interested in seeing the A15 issue fixed though as I almost always just use JiffyDOS.

Neukam, 2021-07-26:
On 326298 and 250407 boards the serial bus reset is tied to the internal reset circuit.  On 250425 and 250466 boards, the serial reset is the EXTRST signal buffered by Q3 and which is separated from the internal reset circuit by U8.

Neukam, 2021-07-26:
It's also important to note that the 326298 boards have a different reset circuit than all the later boards and can't just be pulled low without modifying the reset circuit first.

bwack, 2021-07-27:
I have the sks64 on a breadboard, and I see the same issue as you see. A15 is always low at power on in 8 bank longboard mode.

bwack, 2021-07-27:
I released a new firmware that fixes this bug. The A15 bit was not stored on eprom.
https://github.com/bwack/C64-Switchless-Multi-Kernal-27C256-adapter/releases/tag/fw1.4

Neukam, 2021-07-27:
Thanks!  I've tested the ATTINY45 and ATTINY85 RGB precompiled versions and they both work as expected.  If you or anyone else wants to put one in a 1541, I recommend reducing PRESSTIME to 8 and HOLDTIME to 18 to make changes and resets faster.

bwack, 2021-07-30:
I added serial data to the reset signal, and a listener on the same line :) WIll try this in a C64 and a 1541 drive soon:)
https://twitter.com/bwack77/status/1420889235939278848?s=20

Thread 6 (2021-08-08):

Cannot find Gerber files

vk5zea, 2021-08-08:
I hope this is not a silly question... but I cannot seem to find Gerber files for the SKS64 Switchless Multi Kernal Switcher
Can someone point me to the right place to find them?

bwack, 2021-08-08:
They are under Releases.
https://github.com/bwack/C64-Switchless-Multi-Kernal-27C256-adapter/releases/tag/V1.21
May I ask which board you are making ? Are you making for the 1541C/II, if so, I'm currently working on a solution for the 1541C/1541-II.

vk5zea, 2021-08-08:
Thank you for that.  I did see mention of a Releases Tab, but didn't see it.
I'm planning on making Kernal switchers for both C64 Long and Short Boards.

Closed 2021-10-20.

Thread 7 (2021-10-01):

Newer releases not working with shortboard v1.0 PCB

glbyers, 2021-10-01:
I have the SKS in a 250469 with the revsion 1.0 PCB. I built this about a year ago and asidfe from black screen on initial boot, would work fine after changing kernel or reset. I saw v1.2 release should fix this, so updated to the latest release (v1.4). Since doing that, I don't seem to be able to do the initial setup. On power up, I get cycles of 1 long flash followed by 2 short flashes and it doesn't matter how long I hold RESET for on power up, that does not change. I downgraded to release 1.2, but still observed the same behaviour. I'm using a W27C512 with BASIC followed by 7 kernels and an ATTINY85, the same setup that previously worked. I re-flashed v1.1 and I was again able to run the setup and aside from black screen at startup, works fine again after initial reset or kernel change.

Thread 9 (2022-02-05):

Unable to get 1.6 working

StormTrooper, 2022-02-05:
I've got a longboard 250425 and using a attiny85 with a single LED.

Version 1.4 works fine, but I have now tried to upgrade to 1.6 and its programmed fine, but I cannot it working.

On bootup I hold the restore in  and it does not go into setup mode. Doing the same on 1.4 works fine.

Are there any hardware changes that need to be done between 1.4 and 1.6?

hansdals, 2022-02-08:
No.
You have: the longboard version, and have flashed the SKS64_SKETCH_fw_1.6_RED_attiny85.hex firmware ?
I haven't tested with a single led. Not sure why it should be a problem. When I have time I can have a look, unless someone else here beats me to it :)

bwack, 2022-02-08:
No.
You have: the longboard version of the sks, and have flashed the SKS64_SKETCH_fw_1.6_RED_attiny85.hex firmware ?
I haven't tested with a single led. Not sure why it should be a problem. When I have time I can have a look, unless someone else here beats me to it :)

StormTrooper, 2022-02-08:
Yes, I flashed SKS64_SKETCH_fw_1.6_RED_attiny85.hex and used on a longboard.  Haven't managed to do any other testing yet on a shortboard or with RGB led yet.

AtomicRPM, 2023-04-15:
Works for me.  Using a PIC12F629 though.

kevinherzig, 2024-03-10:
I know this was opened long ago, but an issue on newly built boards for me too.  Have to use 1.4 to get this to work.  Will take a look at the code.

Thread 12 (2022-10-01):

Problem on 250469 all kernals not switched

danko79, 2022-10-01:
Hi, i have a C64c mainboard short 250469 and flashed SKS64_SKETCH_fw_1.6_RGB_attiny85.hex on attiny85-20pu with TL866II programmer and have pcb short rev 1.1 with flash W27c512-45z flashed the 7 kernals plus basic, BASIC_KERNAL_EXOS_SPEEDDOS_JIFFYDOS_JAFFYDOS_DOLPHIN_SPEEDDOS.bin the problem is the multi kernal adapter switched only the last 4 kernal the others banks not switched, i can't figure out where i am wrong should 7 kernal work?

bwack, 2022-10-02:
Here are the instructions from the User Guide about choosing long/short board and how many banks. Befor you power on the machine, you hold restore while you power up the machine. After 5 seconds of holding restore you should see a white flash. The speed of the flashes indicate configuration. see below.

```
Setup
After installing the firmware in the SKS64, and installing it in the computer you can enter the setup menu
by holding RESTORE while powering on the machine. Continue to hold RESTORE until the LED flashes white.
Tap RESTORE to rotate through all the four possible setups. Two flashes, short or long, can be
seen periodically. They indicate the selected setup where the first flash is the motherboard form factor, and
the second flash is related to the size of the EPROM used.
	LONG – SHORT	longboard, 4 banks
	LONG – LONG	longboard, 8 banks
	SHORT – SHORT	shortboard, 3 banks
	SHORT – LONG	shortboard, 7 banks.
	LOONG		1541 mode, 2 banks.
Hold RESTORE again for 5s to store setup in the ATtiny's EEPROM, and the main program starts.
```

danko79, 2022-10-02:
Yes works! Many Thanks.

Closed 2022-10-02.

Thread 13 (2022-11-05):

SKS64 in 1541C is not working

synattack, 2022-11-05:
I have a short and longboard C64 both with your SKS64 solution, and both are working fine (ATTINY85, Firmware 1.6 in combination with an RGB LED).

Because I also own a 1541C drive I tried installing the SKS64 board for a 1541C/1541-II so it switches between stock and Jiffy ROM automatically.

Unfortunately, I still didn't succeed in getting this to work. The RGB LED and/or the kernel in the 1541C isn't changing when I do a SKS64 reset on my C64 (tried both the shortboard and longboard C64).

The board for the 1541C is build as described in your manual (shortboard version, no U2 and bridged JP1 JP2 and JP4). The RST is connected to R12

As EEPROM I used a W27C512 (could this be the issue?) which has the following 16K ROMs: 1541C.251968-02.bin (http://www.zimmers.net/) + JiffyDOS_C1541.bin (since I'm using a 27C512 I copied them twice).

Do you have any tips on how to troubleshoot this?

bwack, 2022-11-06:
Have you seen my videos and the documentation ?
https://www.youtube.com/watch?v=BPDDgQBmcGY&list=PLtQOf_JULmrQTB7486X5pXG1Aaxbl_RdE&index=13

synattack, 2022-11-09:
I watched the 1541C video, but missed the other one ("Commodore 1541 drive with kernal switcher controlled by the C64"). If I understand correctly there is a difference in how the RST signal works between the different boards... But I also have a 250407 board so coming weekend I will test with this board.

synattack, 2022-11-18:
When using a 250407 board everything is working fine. Maybe it's an idea to add a comment in the manual about the different RST signals in the different C64 boards?

bwack, 2022-11-18:
Ok I can add that to the manual. The reset signalling is experimental, and i know it doesnt work over all the numerous models of motherboards and disk drives.

bwack, 2022-11-18:
Thanks for finding this out.

bwack, 2022-11-20:
It's not clear what is the cause of this, and I'm trying to resonate to a solution.

I notice that the 250469 (shortboard)
1. has a split reset on the motherboard
2. only one of them is driven by an open collector driver, and the other a push pull driver (74LS14).
3. It SKS64 reset cannot work if it is connected to a push pull driver.
4. The suggested connection point on the motherboard, as shown on the readme (and below here), is then false because of 3. . Connected to 3. it will only reset the C64. Connecting it the other side of U22 will drive both EXTRST and INRST, but will not work because of 2. . However connecting it to U23 pin 5 (input) could work, though notice this connection is a slow rise (power on reset) thing where a capacitor is slowly charged. So the mcu would need to both push and pull when it communicates over RST. Not user if the firmware is doing that.

The C64C reset (U23 is 74LS14, and U22 is 74LS06):
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

bwack, 2022-11-20:
I had think about this. serial transfer on a 220uF capacitor line isn't such a great idea lol.
Though, why wouldn't we just connect INRST and EXTRST together?

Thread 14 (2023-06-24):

Bricked after setting up for longboard, 8 kernals

d0plr, 2023-06-24:
Using firmware from latest release  (SKS64_SKETCH_fw_1.6_RED_attiny85.hex), and a W27C512 EEPROM in a 250407 board.
At first the adapter was working fine, but could only access 4 kernals.

I entered setup to configure for longboard 8 kernals  (long-long led flashes) and saved.  Since then I get a black screen on the c64.  I can enter the setup mode of the switcher again, but no matter what I do the c64 won't boot anymore.

Removed the switcher, put back my orignal ROM, black screen again.  My C64 is now dead.

d0plr, 2023-06-24:
I let the c64 cool for a while, then used a deadtest & diagnostic cartridge. RAM, ROM & PLA tests passed. So I removed the cartridge and now the c64 boots fine. Looks like it fixed itself !
I put back the sks64, and it also works as expected, I can switch between 8 kernals. No idea what happened, but I won't enter setup again :-)
Anyway thanks for sharing your work !

Closed 2023-06-24.

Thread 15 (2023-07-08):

1.6 RGB Attiny85 hex don't work on C64-C (pal)

gh0stless, 2023-07-08:
I've equipped (pal) two C64--C (short board) here and noticed that SKS64_SKETCH_fw_1.6_RGB_attiny85.hex doesn't work (on both). Downgrade to 1.4 hex works.

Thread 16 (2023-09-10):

0xDE read/write after reset

robin-raymond, 2023-09-10:
````c
while (ss.available()) {
    uint8_t data = ss.read();
    if (data==0xde) {
      delay(1);
      if (ss.available()) {
        rom=(ss.read());
        flashcounter=0;
        set_ledcolor(rom);
      }
    }
  }
````

I have a question regarding this code, and it's probably my lack of understanding. From what I see the loop enters and continues to look for 0xDE from the serial bus (which is sent after a remote side sends during a rom switch). I understand the IEC does a transmit/receive handshake which effectively isn't being monitored by the code and instead the code defaults to listen except when the "RESTORE" line changes the ROMs (so a temporary Tx happens then the state machine goes back to listen).

What I don't understand is why 0xDE is being monitored forever (or if somehow the monitoring is disabled). If a transmitted data chunk contains the sequence 0xDE in it, wouldn't this be interpreted as a ROM switch?

What I checked for:
- I don't see an exit to `loop()` [AFAIK the loop goes on forever in the code]
- I don't see `ss.ignore();` [which would ignore all the received bytes]
- I don't see `ss.end();` [which would end the listener]
- I don't see going back into Tx mode which would cause contention (and that doesn't appear to be the case)
- I don't see a `goto label;` from the loop that would skip the receive
- I don't see logic which would only look for 0xDE at the start of a serial command sequence [which in theory should never have a 0xDE as the first byte in the control codes] (but maybe I'm missing some subtleness in the code)
- I don't see control flow logic which would skip the `ss.read();` if it had data available
- AFAIK the 1541 ROM isn't shadowed to RAM after reset which would have the side effect of a switch to effectively be ignored (which I couldn't see happening anyway given that the 1541 only has 2K of RAM anyway).

Yes, I saw clearly in your video that a game loaded and I can't imagine it didn't contain a single 0xDE value sequence followed by a random byte that would not cause some issue, or that someone else using your switcher hasn't hit an issue.

So how is this magic happening where a 0xDE byte in the serial protocol doesn't cause all sorts of random issues?

bwack, 2023-09-11:
They are listening and sending on the reset line.

bwack, 2023-09-11:
Maybe you missed the first video
https://youtu.be/BPDDgQBmcGY?si=ZJ5OWkKWSvlbuMEU

robin-raymond, 2023-09-11:
I watched that video twice. I understand they read/write on the same pin as this a half duplex IEC serial line. The concern was not with the listening/sending. The concern was with the continuous / forever monitoring for 0xDE byte in the listened serial stream.

bwack, 2023-09-11:
No its not the serial line, it's the reset line in the serial cable.

robin-raymond, 2023-09-11:
Ah, sorry, that’s an important distinction. Not sure why my brain glossed over that super important detail. Likely because I didn’t think anyone would use this line doubled as a Tx/Rx even though you did show it in the video. Do we know how all IEC devices will respond to a pulse of high/lows prior to a full reset, including devices like the printers, SD2IEC and Ultimate II? I presume they would be ok because in early commodores the IEC was directly connected to the CPU which means it would receive the same reset as the expansion port (I think), and I could see that port potentially having button debouncing issues when a reset button was in use by a button connected in an expansion cartridge. Although Ultimate II might never expect a reset to happen given its in control of the reset line being plugged into the expansion port at the time of use. I don’t know its internal circuitry. Do you anticipate any issues with other non disk devices or other virtualized ones? Obviously the Ultimate II wouldn’t detect this and switch roms, I get that. I know virtually nobody will connect a printer anymore but there are other potential IEC devices.

bwack, 2023-09-11:
No worries.
I haven't tested with printers, SD2IEC or ulitmate II. I also presume they will be ok since the will be held in reset after the pulsetrian of serial data is transfered. I don't know, and I don't think it will be a problem.

robin-raymond, 2023-09-11:
I too think it will be fine. It might be that some IEC + cartridges may have compatibility issues on older C64s where the RESET is directly wired into the CPU along with the external port RESET (because that might do something strange) but if we do a long enough RESET low pull after a bank switch then it shouldn't be a problem (which you'd have to do to clean out active running assembly programs anyway). The expansion port pin is "in" not "out" so I don't know if any cartridge ever reads that RESET pin (at least they shouldn't) where the IEC RESET and expansion RESET are linked together in older boards. Even then I think any possible problems will be rare and obscure. I'll be sure to test with Ultimate II / SD2IEC and see how they behave as soon as I get my boards and have some time to test. Thanks!

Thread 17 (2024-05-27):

Gerber for shortboard V1.1

C64Retro, 2024-05-27:
Hi would you please be able to post the gerber for the shortboard V1,1?

Regards BT

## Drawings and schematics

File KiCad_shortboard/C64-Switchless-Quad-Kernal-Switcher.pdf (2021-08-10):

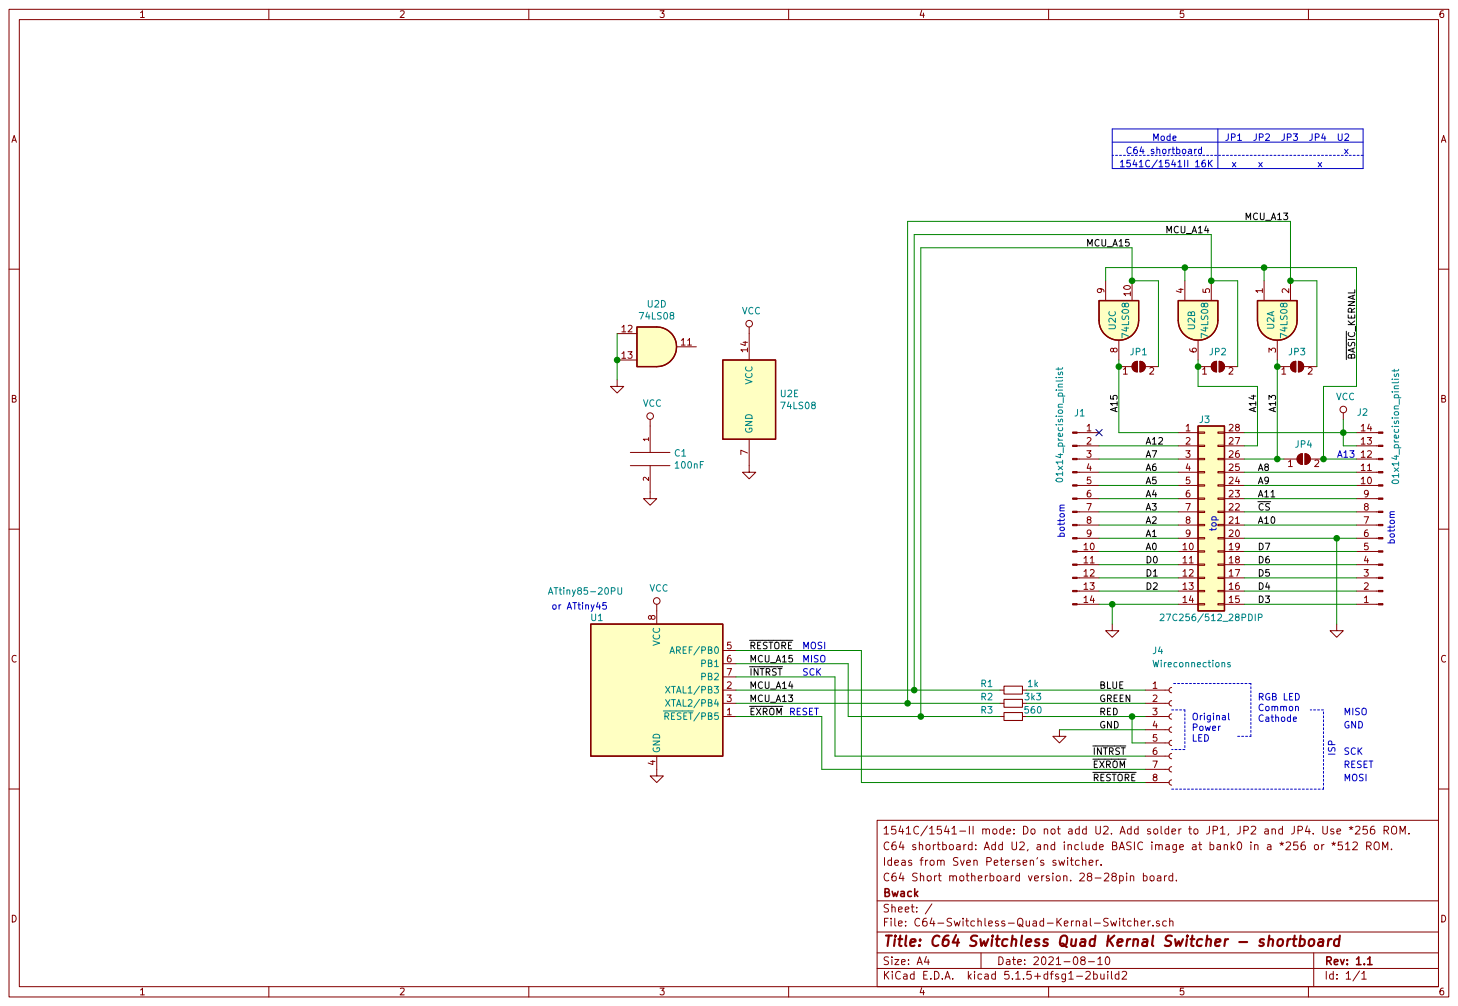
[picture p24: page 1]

RESET ISP RGB LED

Ideas from Sven Petersen's switcher. C64 shortboard: Add U2, and include BASIC image at bank0 in a *256 or *512 ROM.

File: C64-Switchless-Quad-Kernal-Switcher.sch Sheet: / Bwack C64 Short motherboard version. 28-28pin board.

Id: 1/1 Title: C64 Switchless Quad Kernal Switcher - shortboard

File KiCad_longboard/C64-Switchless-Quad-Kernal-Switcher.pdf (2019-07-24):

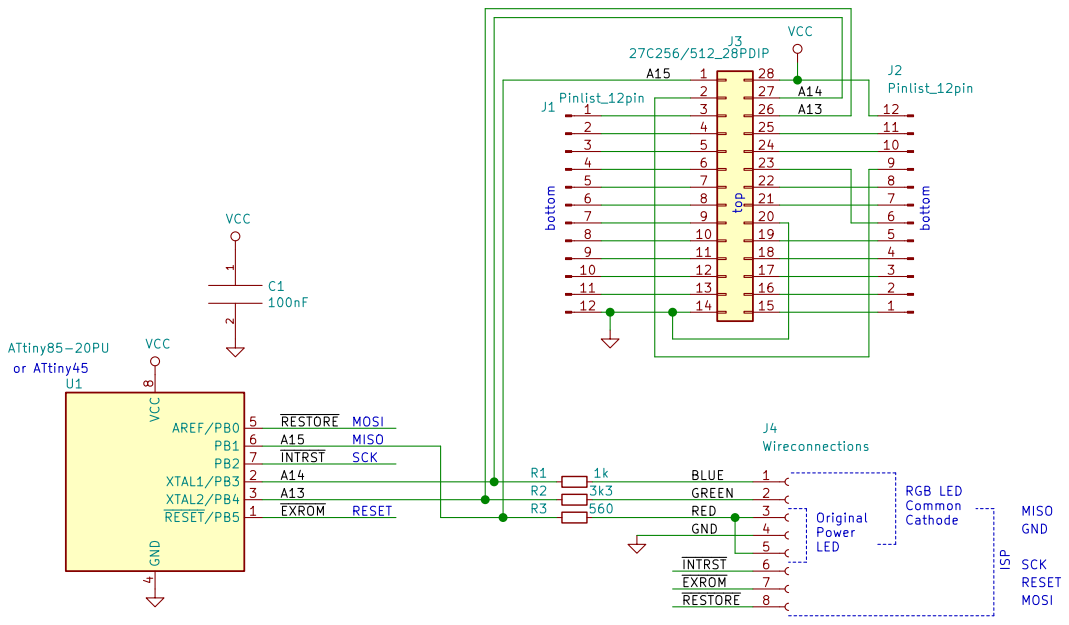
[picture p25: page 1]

2 | 27
3 4 5 6 7 8 9 10 11 12 13 | 26

File: C64-Switchless-Quad-Kernal-Switcher.sch Sheet: / Bwack

Id: 1/1 Title: C64 Switchless Quad Kernal Switcher (SKS64)

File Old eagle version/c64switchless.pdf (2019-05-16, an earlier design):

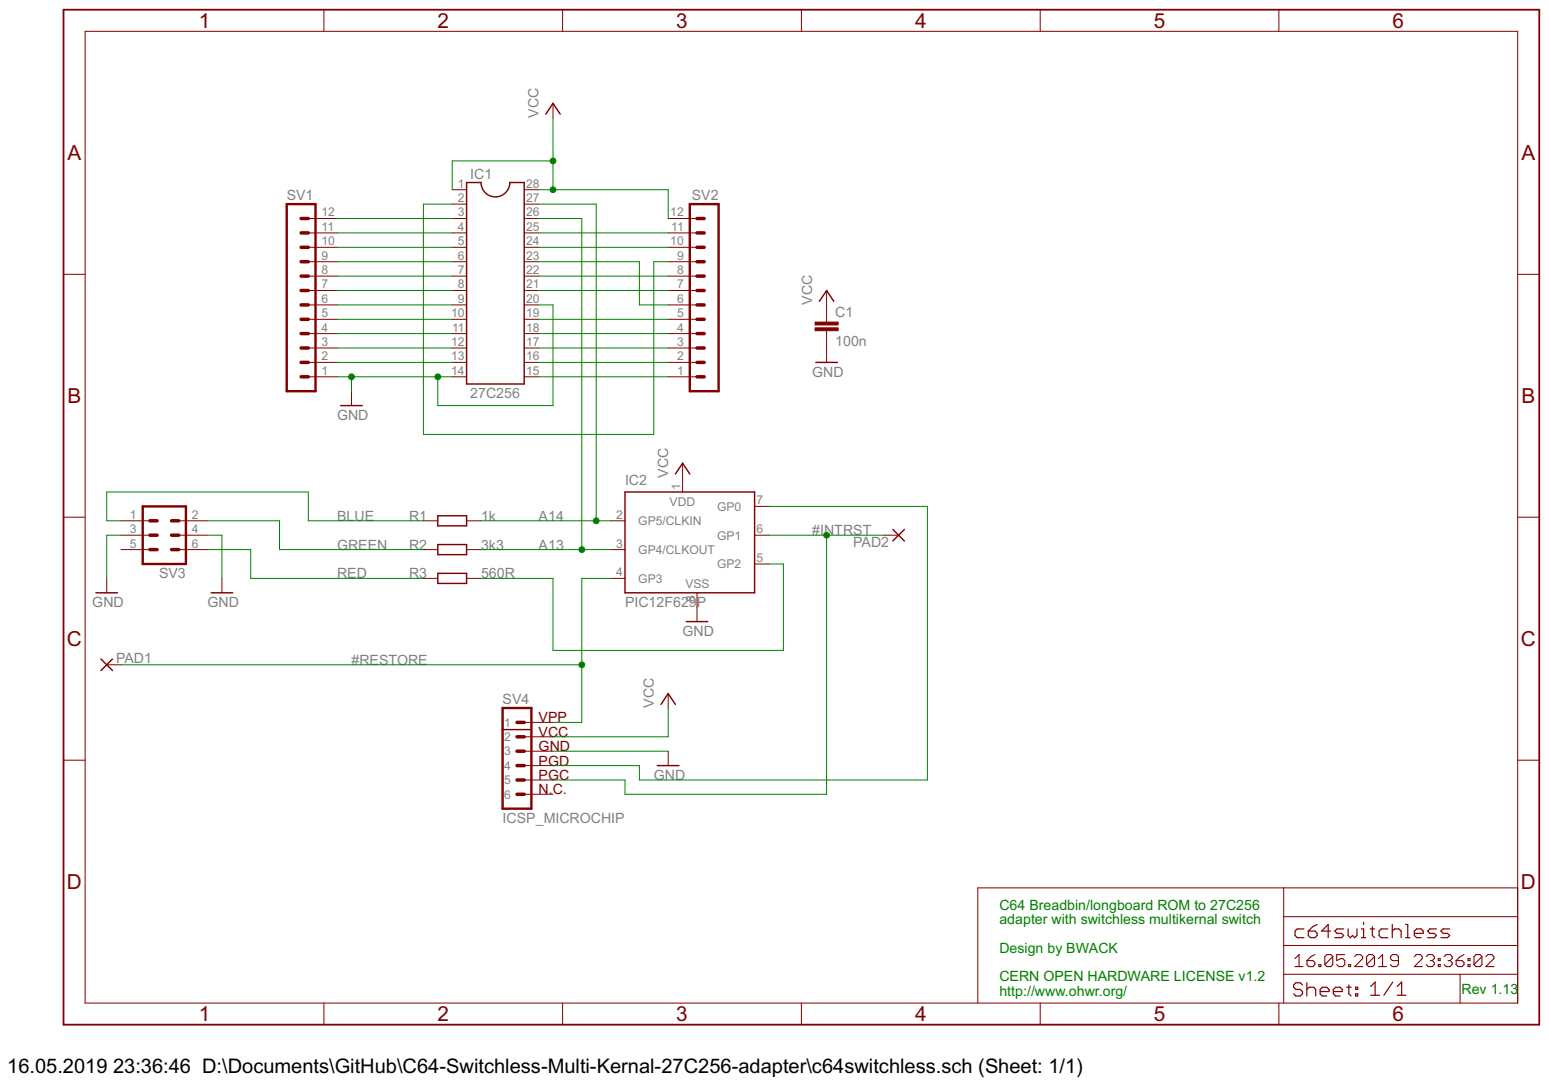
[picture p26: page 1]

C64 Breadbin/longboard ROM to 27C256 adapter with switchless multikernal switch Design by BWACK CERN OPEN HARDWARE LICENSE v1.2 http://www.ohwr.org/

Rev 1.13

16.05.2019 23:36:46 D:\Documents\GitHub\C64-Switchless-Multi-Kernal-27C256-adapter\c64switchless.sch (Sheet: 1/1)

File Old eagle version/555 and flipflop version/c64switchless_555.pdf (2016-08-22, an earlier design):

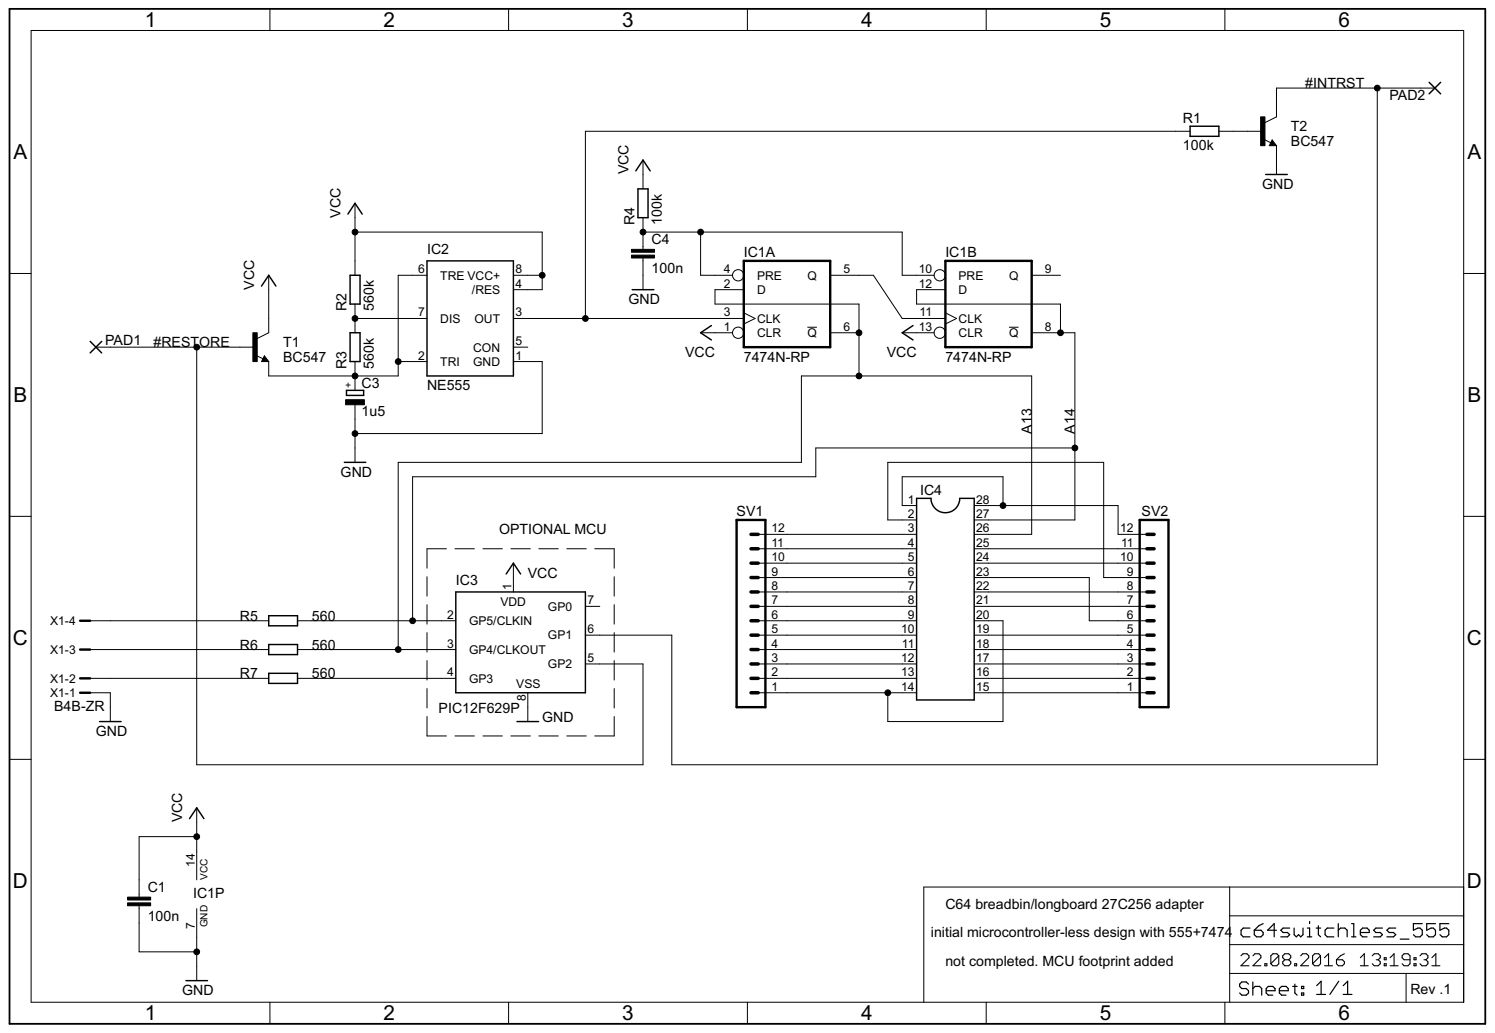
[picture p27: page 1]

C64 breadbin/longboard 27C256 adapter initial microcontroller-less design with 555+7474 not completed. MCU footprint added

Rev .1

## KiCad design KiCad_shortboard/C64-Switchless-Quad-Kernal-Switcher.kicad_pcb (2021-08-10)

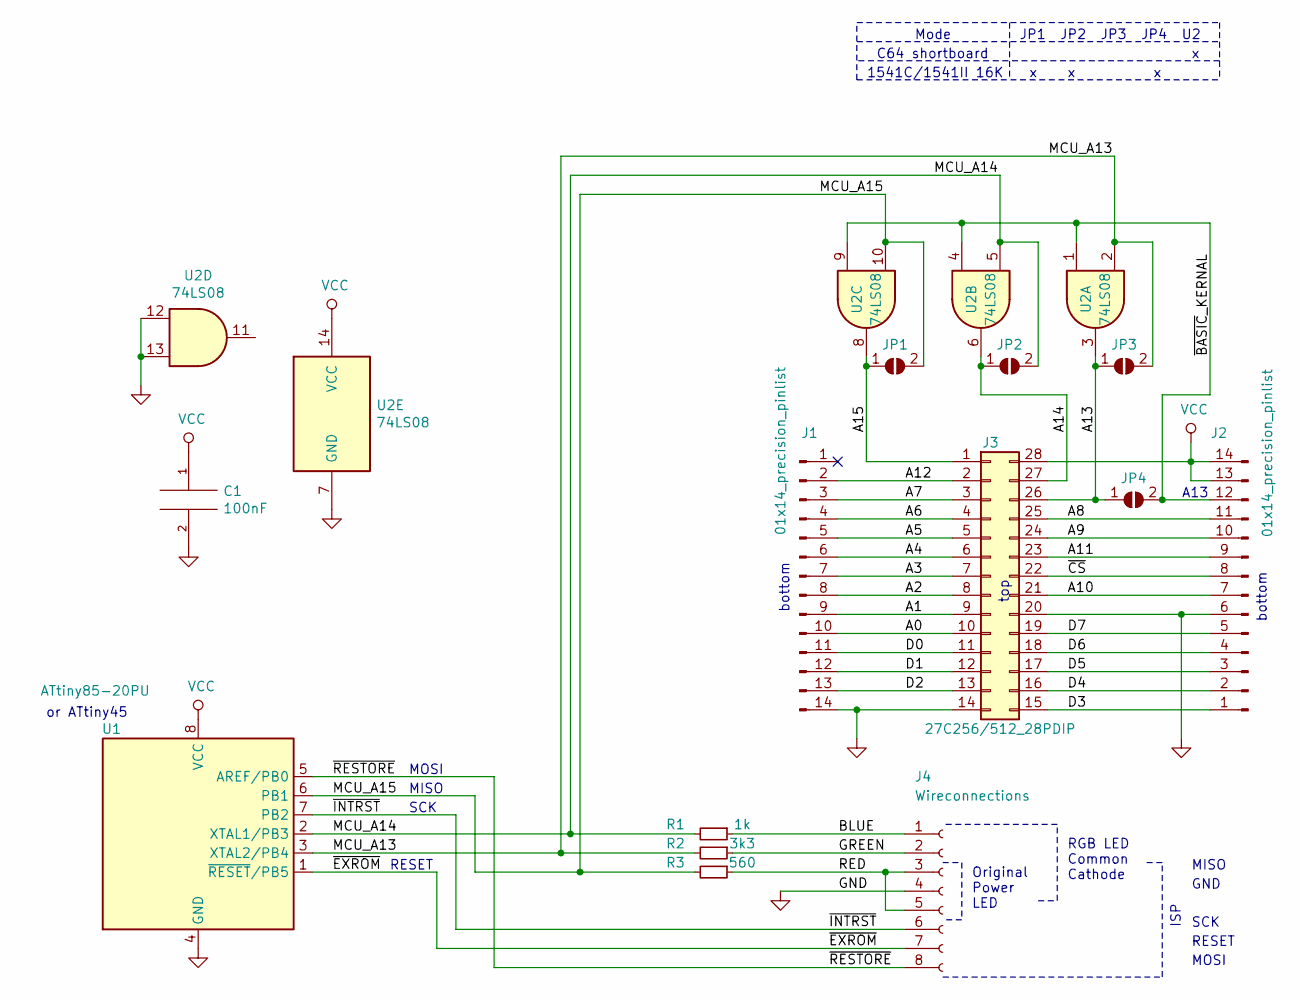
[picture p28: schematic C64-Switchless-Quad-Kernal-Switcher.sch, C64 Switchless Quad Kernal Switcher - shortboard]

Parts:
C1: 100nF; R_0805_2012Metric_Pad1.15x1.40mm_HandSolder
J1, J2: 01x14_precision_pinlist; PinHeader_1x14_P2.54mm_Vertical
J3: 27C256/512_28PDIP; DIP-28_W15.24mm_Socket
J4: Wireconnections; PinHeader_1x08_P2.54mm_Horizontal
JP1, JP2, JP3, JP4: SolderJumper_2_Open; J_0402
R1: 1k; R_0805_2012Metric_Pad1.15x1.40mm_HandSolder
R2: 3k3; R_0805_2012Metric_Pad1.15x1.40mm_HandSolder
R3: 560; R_0805_2012Metric_Pad1.15x1.40mm_HandSolder
U1: ATtiny85-20PU; DIP-8_W7.62mm_Socket
U2: 74LS08; SOIC-14_3.9x8.7mm_P1.27mm

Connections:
/A0: J1.10, J3.10
/A1: J1.9, J3.9
/A2: J1.8, J3.8
/A3: J1.7, J3.7
/A4: J1.6, J3.6
/A5: J1.5, J3.5
/A6: J1.4, J3.4
/A7: J1.3, J3.3
/A8: J2.11, J3.25
/A9: J2.10, J3.24
/A10: J2.7, J3.21
/A11: J2.9, J3.23
/A12: J1.2, J3.2
/A13: J3.26, JP3.1 (A), JP4.1 (A), U2.3
/A14: J3.27, JP2.1 (A), U2.6
/A15: J3.1, JP1.1 (A), U2.8
/BLUE: J4.1, R1.1
/D0: J1.11, J3.11
/D1: J1.12, J3.12
/D2: J1.13, J3.13
/D3: J2.1, J3.15
/D4: J2.2, J3.16
/D5: J2.3, J3.17
/D6: J2.4, J3.18
/D7: J2.5, J3.19
/GREEN: J4.2, R2.1
/MCU_A13: JP3.2 (B), R2.2, U1.3 (XTAL2/PB4), U2.2
/MCU_A14: JP2.2 (B), R1.2, U1.2 (XTAL1/PB3), U2.5
/MCU_A15: JP1.2 (B), R3.2, U1.6 (PB1), U2.10
/RED: J4.3, J4.5, R3.1
/~BASIC~_KERNAL: J2.12, JP4.2 (B), U2.1, U2.4, U2.9
/~CS~: J2.8, J3.22
/~EXROM~: J4.7, U1.1 (~RESET~/PB5)
/~INTRST~: J4.6, U1.7 (PB2)
/~RESTORE~: J4.8, U1.5 (AREF/PB0)
GND: C1.2, J1.14, J2.6, J3.14, J3.20, J4.4, U1.4 (GND), U2.7 (GND), U2.12, U2.13
VCC: C1.1, J2.13, J2.14, J3.28, U1.8 (VCC), U2.14 (VCC)

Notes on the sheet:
bottom
top
SCK
MISO
MOSI
RESET
Original Power LED
RGB LED Common Cathode
ISP
GND
or ATtiny45
A13
JP1 JP2 JP3 JP4 U2
C64 shortboard
Mode
1541C/1541II 16K

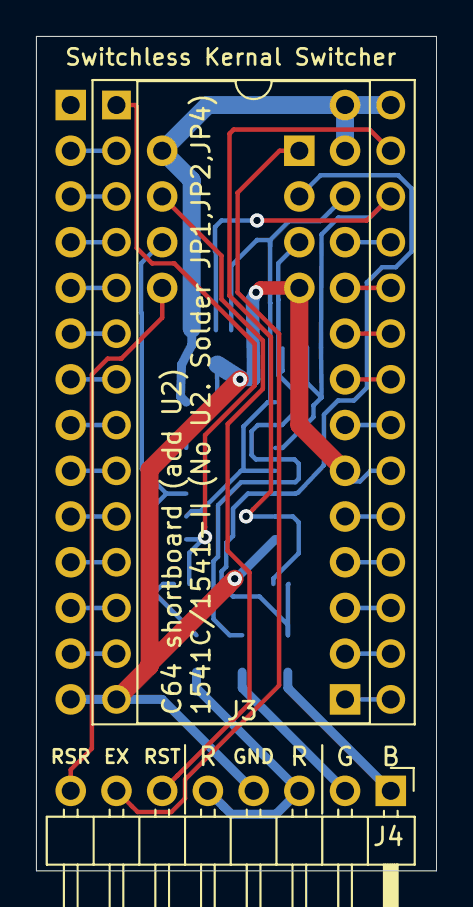
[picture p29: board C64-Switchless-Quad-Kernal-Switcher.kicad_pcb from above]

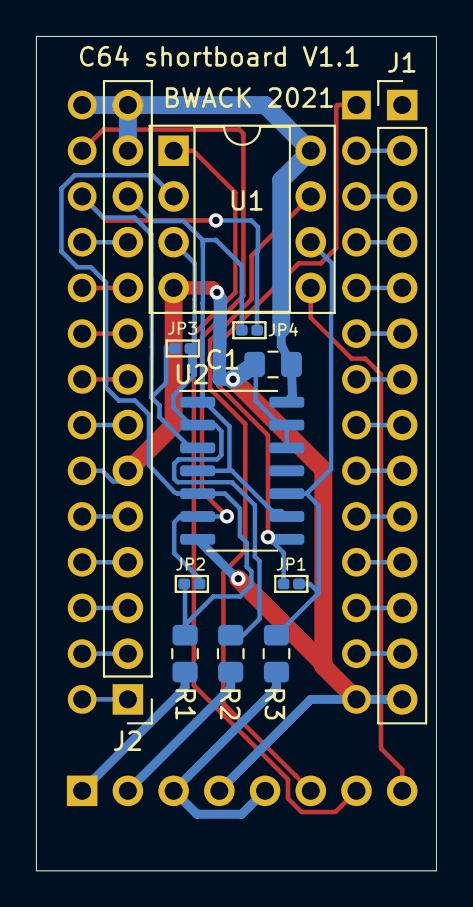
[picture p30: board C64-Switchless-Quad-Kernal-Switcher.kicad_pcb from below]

Board: 2 copper layers, 22.2 x 46.4 mm, 14 parts (12 on the bottom side), 37 nets.

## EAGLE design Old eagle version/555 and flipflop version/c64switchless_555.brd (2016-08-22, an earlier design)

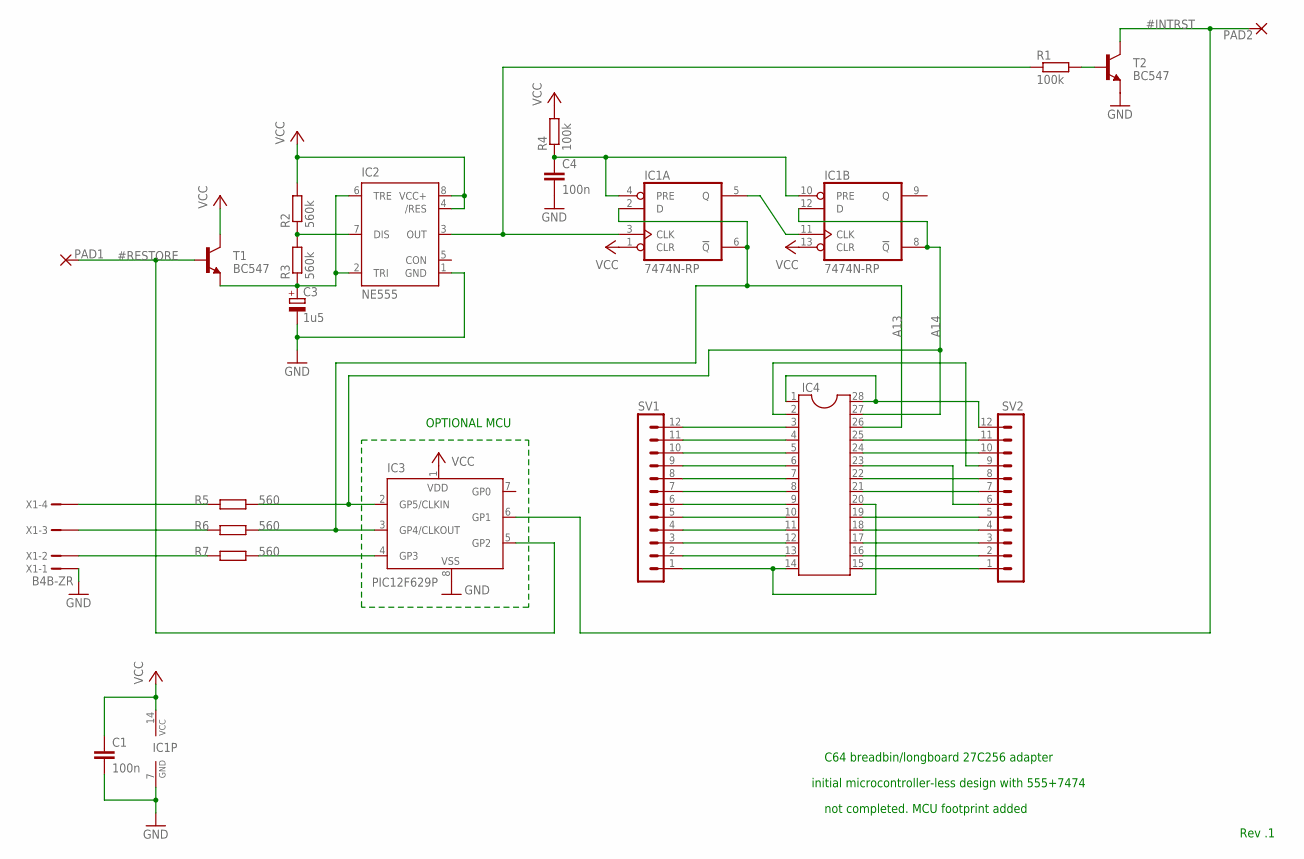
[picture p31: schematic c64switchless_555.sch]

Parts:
C1, C4: 100n; C050-030X075
C3: 1u5; E2,5-6
IC1: 7474N-RP; DIL14-ROUNDPADS
IC2: NE555; DIL-08
IC3: PIC12F629P; DIL8
IC4: DIL28ROUND; DIL28SPECIAL
PAD1, PAD2: WIREPAD2,54/1,0; 2,54/1,0
R1, R4: 100k; 0204/7
R2, R3: 560k; 0204/7
R5, R6, R7: 560; 0204/7
SV1, SV2: MA12-1ROUND
T1, T2: BC547; TO92
X1: B4B-ZR

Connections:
#INTRST: IC3.6 (GP1), PAD2.1, T2.3 (C)
#RESTORE: IC3.5 (GP2), PAD1.1, T1.2 (B)
A13: IC1.2 (D), IC1.6 (!Q), IC3.3 (GP4/CLKOUT), IC4.26, R6.2
A14: IC1.8 (!Q), IC1.12 (D), IC3.2 (GP5/CLKIN), IC4.27, R5.2
GND: C1.2, C3.-, C4.2, IC1.7 (GND), IC2.1 (GND), IC3.8 (VSS), T2.1 (E), X1.1
unnamed: IC4.14, IC4.20, SV1.1
unnamed: IC4.13, SV1.2
unnamed: IC4.12, SV1.3
unnamed: IC4.11, SV1.4
unnamed: IC4.10, SV1.5
unnamed: IC4.9, SV1.6
unnamed: IC4.8, SV1.7
unnamed: IC4.7, SV1.8
unnamed: IC4.6, SV1.9
unnamed: IC4.5, SV1.10
unnamed: IC4.4, SV1.11
unnamed: IC4.3, SV1.12
unnamed: IC4.15, SV2.1
unnamed: IC4.16, SV2.2
unnamed: IC4.17, SV2.3
unnamed: IC4.18, SV2.4
unnamed: IC4.19, SV2.5
unnamed: IC4.21, SV2.7
unnamed: IC4.22, SV2.8
unnamed: IC4.24, SV2.10
unnamed: IC4.25, SV2.11
unnamed: IC4.1, IC4.28, SV2.12
unnamed: IC4.23, SV2.6
unnamed: IC4.2, SV2.9
unnamed: R1.2, T2.2 (B)
unnamed: C3.+, IC2.2 (TRI), IC2.6 (TRE), R3.1, T1.1 (E)
unnamed: IC2.7 (DIS), R2.1, R3.2
unnamed: IC3.4 (GP3), R7.2
unnamed: IC1.5 (Q), IC1.11 (CLK)
unnamed: C4.1, IC1.4 (PRE), IC1.10 (PRE), R4.1
unnamed: R5.1, X1.4
unnamed: R6.1, X1.3
unnamed: R7.1, X1.2
unnamed: IC1.3 (CLK), IC2.3 (OUT), R1.1
VCC: C1.1, IC1.1 (CLR), IC1.13 (CLR), IC1.14 (VCC), IC2.4 (/RES), IC2.8 (VCC+), IC3.1 (VDD), R2.2, R4.2, T1.3 (C)

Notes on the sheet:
C64 breadbin/longboard 27C256 adapter
initial microcontroller-less design with 555+7474
not completed. MCU footprint added
OPTIONAL MCU
Rev .1

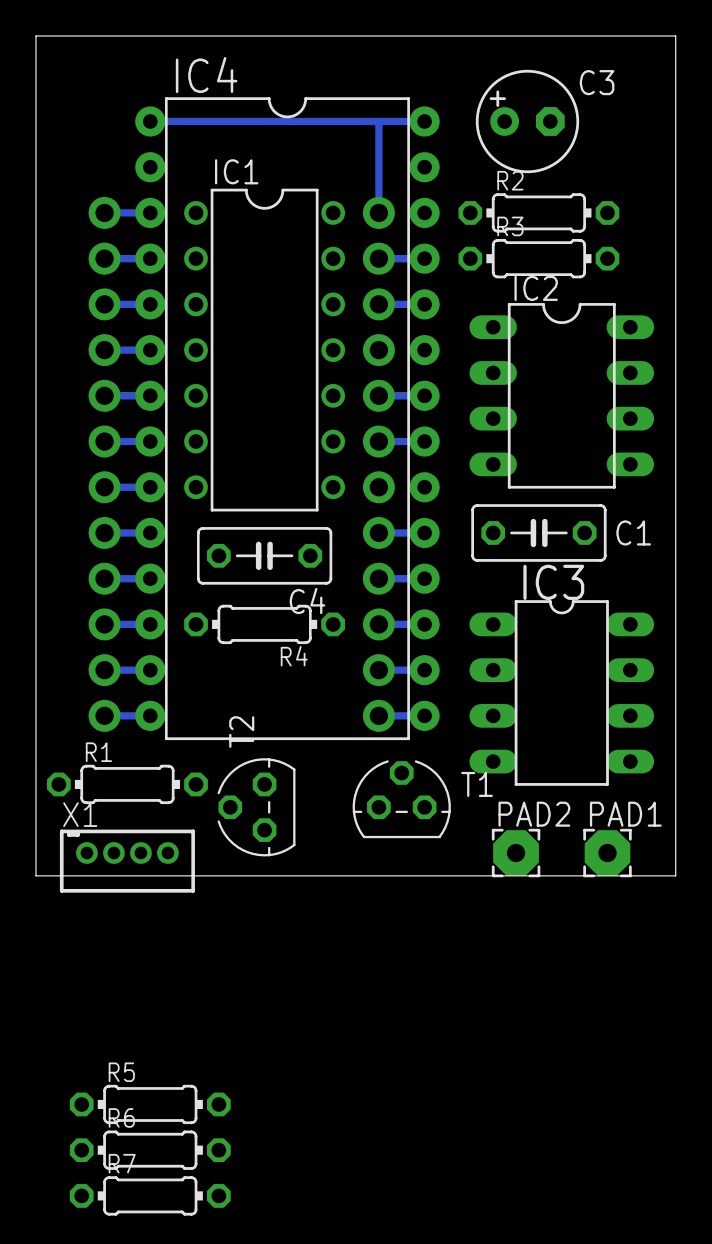
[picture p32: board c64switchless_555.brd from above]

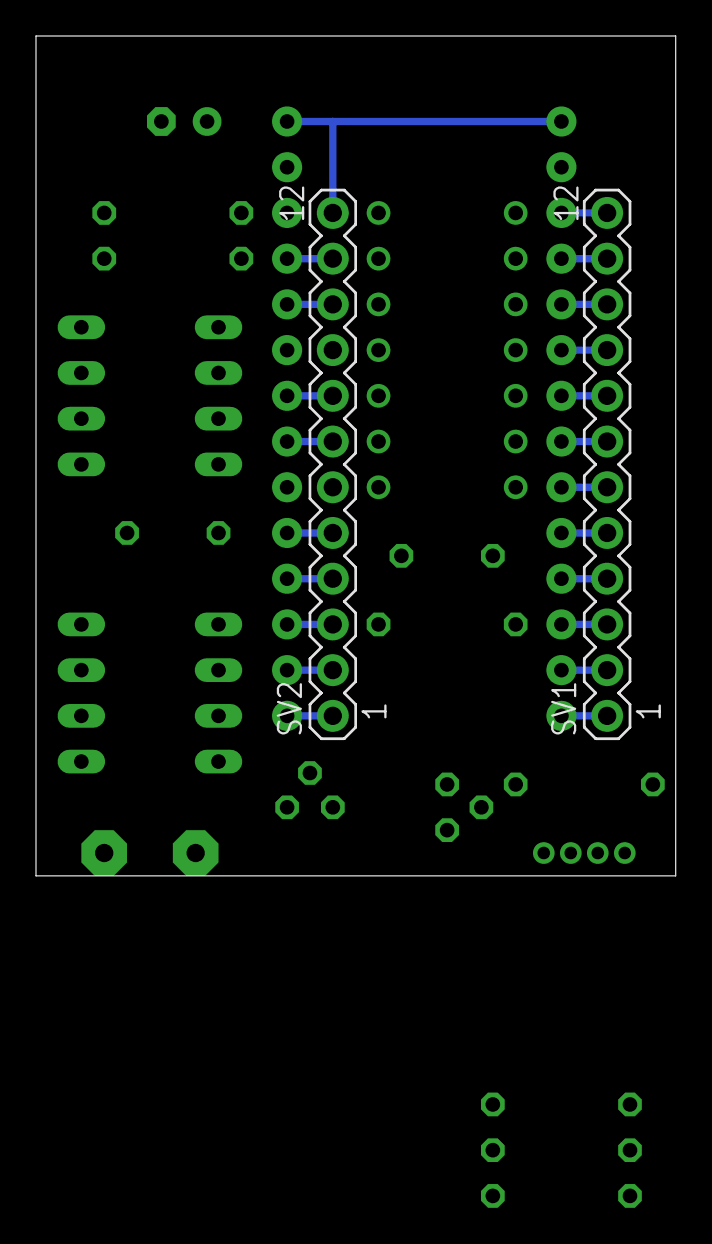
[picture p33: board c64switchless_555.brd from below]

Board: 2 copper layers, 35.5 x 46.7 mm, 21 parts (2 on the bottom side), 40 nets.

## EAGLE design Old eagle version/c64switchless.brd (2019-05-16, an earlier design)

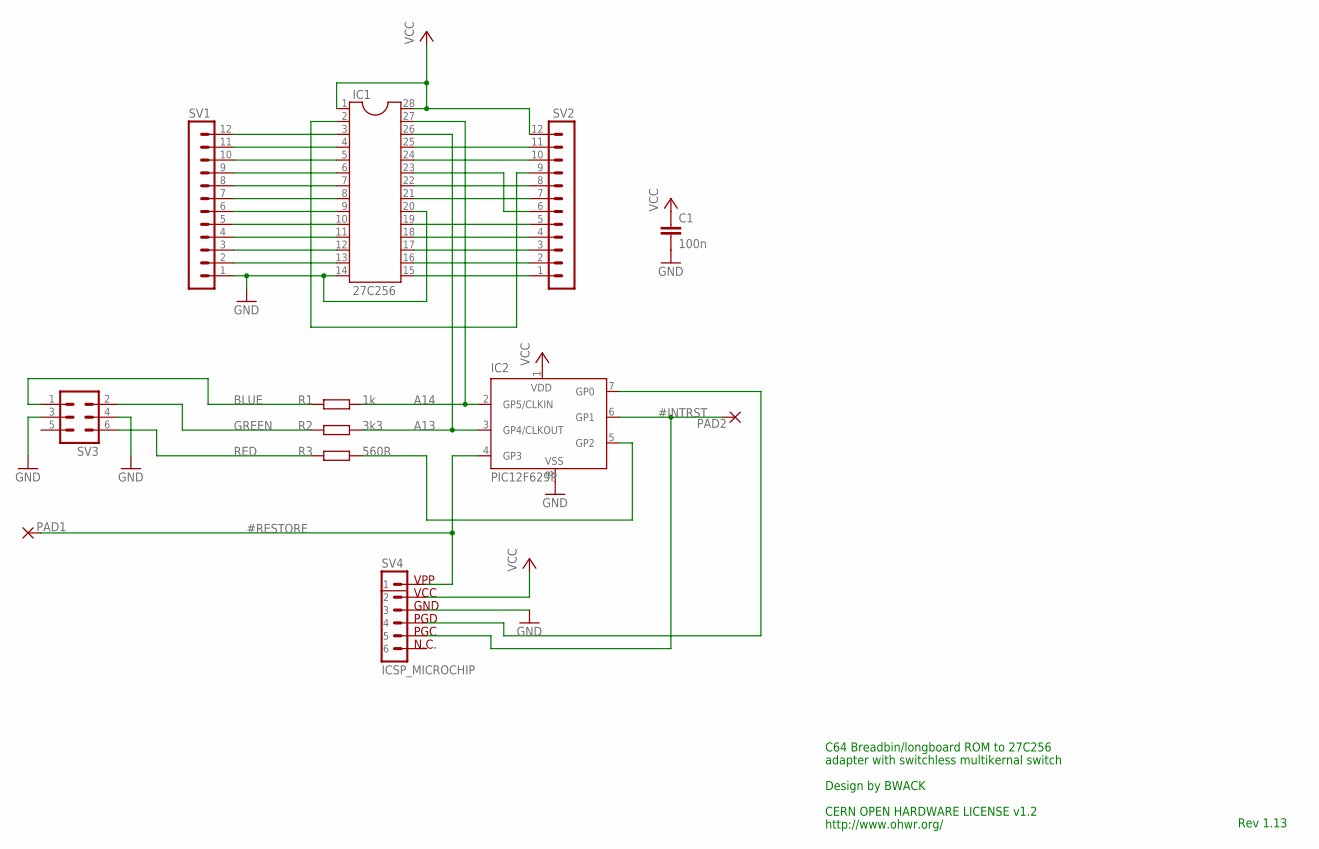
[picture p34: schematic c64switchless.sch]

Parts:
C1: 100n; C025-024X044
IC1: 27C256; DIL28SPECIAL
IC2: PIC12F629P; DIL8
PAD1, PAD2: WIREPAD1,6/0,9; 1,6/0,9
R1: 1k; 0207/10
R2: 3k3; 0207/10
R3: 560R; 0207/10
SV1, SV2: MA12-1ROUND
SV3: MA03-2
SV4: ICSP_MICROCHIP

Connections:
#INTRST: IC2.6 (GP1), PAD2.1, SV4.5
#RESTORE: IC2.4 (GP3), PAD1.1, SV4.1
A13: IC1.26, IC2.3 (GP4/CLKOUT), R2.2
A14: IC1.27, IC2.2 (GP5/CLKIN), R1.2
BLUE: R1.1, SV3.1
GND: C1.2, IC1.14, IC1.20, IC2.8 (VSS), SV1.1, SV3.3, SV3.4, SV4.3
GREEN: R2.1, SV3.2
unnamed: IC2.7 (GP0), SV4.4
unnamed: IC1.13, SV1.2
unnamed: IC1.12, SV1.3
unnamed: IC1.11, SV1.4
unnamed: IC1.10, SV1.5
unnamed: IC1.9, SV1.6
unnamed: IC1.8, SV1.7
unnamed: IC1.7, SV1.8
unnamed: IC1.6, SV1.9
unnamed: IC1.5, SV1.10
unnamed: IC1.4, SV1.11
unnamed: IC1.3, SV1.12
unnamed: IC1.15, SV2.1
unnamed: IC1.16, SV2.2
unnamed: IC1.17, SV2.3
unnamed: IC1.18, SV2.4
unnamed: IC1.19, SV2.5
unnamed: IC1.21, SV2.7
unnamed: IC1.22, SV2.8
unnamed: IC1.24, SV2.10
unnamed: IC1.25, SV2.11
unnamed: IC2.5 (GP2), R3.2
unnamed: IC1.23, SV2.6
unnamed: IC1.2, SV2.9
RED: R3.1, SV3.6
VCC: C1.1, IC1.1, IC1.28, IC2.1 (VDD), SV2.12, SV4.2

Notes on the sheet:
C64 Breadbin/longboard ROM to 27C256
adapter with switchless multikernal switch
Design by BWACK
Rev 1.13
http://www.ohwr.org/
CERN OPEN HARDWARE LICENSE v1.2

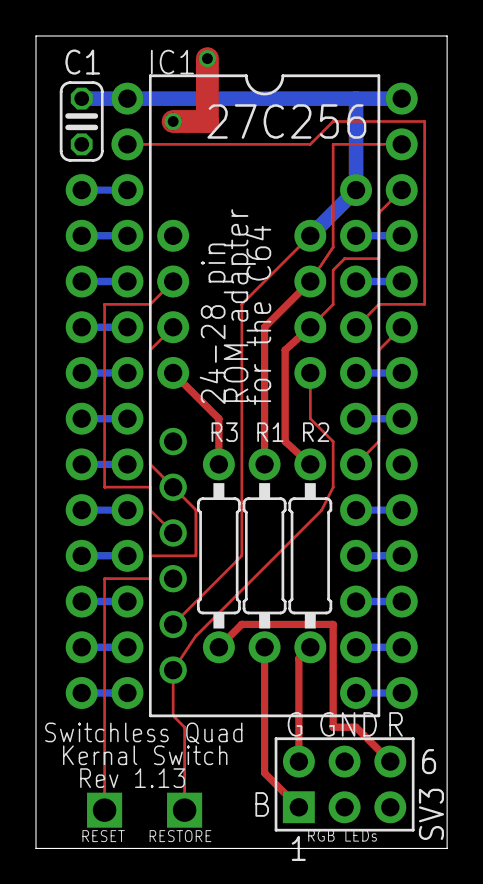
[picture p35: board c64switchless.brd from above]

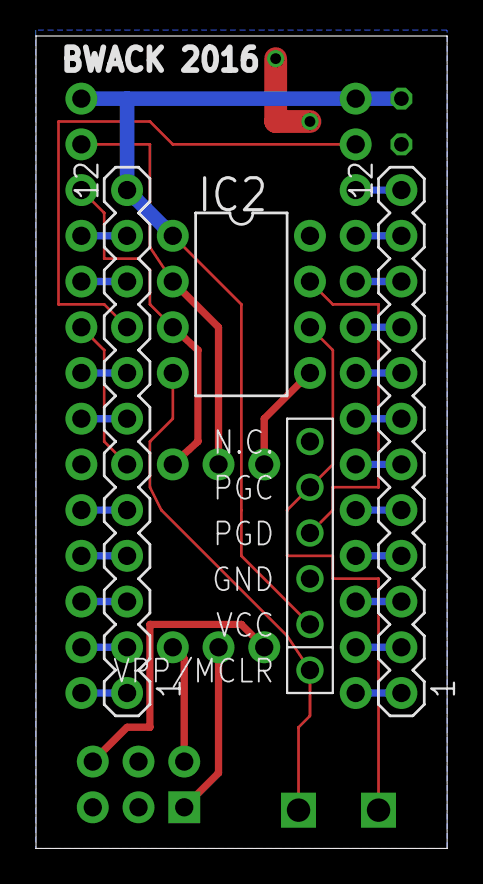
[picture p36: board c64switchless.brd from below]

Board: 2 copper layers, 22.8 x 45.1 mm, 12 parts (4 on the bottom side), 33 nets.

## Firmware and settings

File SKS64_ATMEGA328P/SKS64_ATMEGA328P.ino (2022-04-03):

 /*
 * SKS64 Firmware ported to the Arduino UNO. based on SKS64 Firmware V1.6
 * C64 Switchless Kernal Switcher
 * 
 * Programming:
 * - Board: Arduino Uno
 * 
 *   Usage
 * ==========
 *  Assuming IDLE:
 *  - Hold RESTORE for 5s to perform EXROM-RESET (soft-reset).
 *  - Hold RESTORE for 2s to enter menu.
 *    - Tap RESTORE to change banks.
 *    - Machine resets 2s after releasing RESTORE (hard-reset).
 *    
 *   Setup
 * ===========
 * Select C64 motherboard type and 4 or 8 banks.
 *  - Turn on the computer while holding down the RESTORE key.
 *  - Hold it until the RGB LED starts flashing white twice.
 *  - Tap RESTORE to rotate setup
 *  - Hold RESTORE for about 5s to store setup
 *  
 *  Setup blinkys:
 *     1. LONG SHORT  --> Longboard 4 banks
 *     2. LONG LONG   --> Longboard 8 banks
 *     3. SHORT SHORT --> Shortboard 4 banks
 *     4. SHORT LONG  --> Shortboard 8 banks
 *     5. LOOONG      --> 1541C/1541-II 2 banks
 *
 * History:
 * - 1.1 fixed: red led turned on when EXROM reset (flashcounter not zero)
 * - 1.2 fixed: Set EXROM to input on startup instead of output - otherwise EXROM is held high until first reboot. Thanks Darylrichards!
 * - 1.3 fixed: Removed led flashes at start of program. The delay caused the C64C to not warm start.
 * - 1.4 fixed: A15 always 0 at cold boot in 8 banks longboard mode.
 * - 1.5 new: 1541 mode (2*16k banks). Goes to upper bank when the C64 is in bank1 (jiffydos), and lower bank elsewise.
 * - 1.6 removed startup delay (1s) causing startup issues.
 */

#include <avr/boot.h>
#include <avr/sleep.h>
#include "NeoSWSerial.h"
#include <EEPROM.h>

//#define USE_SLEEPMODE
//#define REDONLY

// I/O
#define RESTORE 8
#define RED 9
#define A13 10
#define A14 11
#define INTRST 7
#define EXROM 6

#define EEPROM_ADDRESS_MODE 1

int exrom_available; // available if fuse bitshighBits 7 is active (low)
int eightmhz;
int counter=0, restore=1, last_press, flashcounter=0, flashdivision, inhibit;
int rom=0, mode=0;
uint16_t flashpattern;

// state machine
#define STATE_INIT 4
#define STATE_SETUP 5
#define STATE_IDLE 0          // Stay in IDLE until RESTORE is held for 0.1s * PRESSTIME.
#define STATE_STILLHOLDING 1  // Continued holding RESTORE goto EXROMRESET, if released goto MENU.
#define STATE_MENU 2          // Single tap resets timeout and changes bank. Timeout goes to RESET.
#define STATE_RESET 3         // Resets machine and go back to IDLE.
#define STATE_EXROMRESET 7    // Resets machine with EXROM and go back to IDLE.
#define PRESSTIME 20   // Presstime in 0.1s to enter menu
#define HOLDTIME 30    // Press for PRESSTIME+HOLDTIME seconds to perform an EXROM-RESET
#define MENUTIMEOUT 20 // Timeout since last press of the restore in menu mode.
int state=STATE_INIT;
int next_state=STATE_INIT;

NeoSWSerial ss( INTRST, INTRST );

volatile uint32_t newlines = 0UL;

static void handleRxChar( uint8_t c )
{
  if (c == '\n')
  newlines++;
}

enum {
  LONGBOARD_4BANKS = 0,
  LONGBOARD_8BANKS,
  SHORTBOARD_3BANKS,
  SHORTBOARD_7BANKS,
  C1541C_1541II,
  MAX_MODES
};

void system_sleep() {
// see http://www.getelectronics.net/arduino-uno-pinout-schematics-and-pin-descriptions.php
// and page56 here https://ww1.microchip.com/downloads/en/DeviceDoc/Atmel-7810-Automotive-Microcontrollers-ATmega328P_Datasheet.pdf
  //PCMSK0 |= bit (PCINT0);
  //PCICR |= bit (PCIE0);
  ADCSRA &= ~_BV(ADEN); // ADC off
  set_sleep_mode(SLEEP_MODE_PWR_DOWN); // sleep mode is set here
  sleep_enable();
  sei();
  sleep_cpu();

  // cpu wakes up here
  cli();
  PCMSK0 &= ~ bit (PCINT0);
  sleep_disable();
  ADCSRA |= _BV(ADEN);
  sei();
}

void flash_led(int led, int times, int duration) {
  for (int i=0; i<times; i++) {
    digitalWrite(led, HIGH);
    delay(duration);
    digitalWrite(led, LOW);
    delay(duration);
  }
}

void set_ledcolor(int _rom) {
  if (mode==C1541C_1541II) {
    if (_rom == 1) {
      digitalWrite(A13, LOW);
      digitalWrite(A14, HIGH);
      digitalWrite(RED, LOW);
    } else {
      digitalWrite(A13, HIGH);
      digitalWrite(A14, LOW);
      digitalWrite(RED, LOW);
    }
  }
  else if (mode==LONGBOARD_8BANKS || mode==SHORTBOARD_7BANKS) {
    // RED is tied to A15 and must be set by rom value
    digitalWrite(A13, _rom&0x01);
    digitalWrite(A14, _rom&0x02);
    digitalWrite(RED, _rom&0x04);
  }
  else if (mode==LONGBOARD_4BANKS || mode==SHORTBOARD_3BANKS) {
    // in 4 bank mode, RED is not tied to A15 and can be used freely
    // In 4 bank mode you are supposed to use *256 ROMS or weird stuff happens.
    // but it is possible to use a *512, just remember to put bank0 at bank4.
    if(_rom==0) {
      digitalWrite(A13, LOW);
      digitalWrite(A14, LOW);
      digitalWrite(RED, HIGH);
    } else {
      digitalWrite(A13, _rom&0x01);
      digitalWrite(A14, _rom&0x02);
      #ifdef REDONLY
      digitalWrite(RED, HIGH);
      #else
      digitalWrite(RED, LOW);
      #endif
    }
  }
}

void rotate_setup() {
  mode++;
  if (mode>=MAX_MODES) mode=0;
}

void rotate_rom() {
  rom++;
  int highestbank=0, startat=0;
  switch (mode) {
    case LONGBOARD_8BANKS:
      highestbank=7;
      startat=0;
      break;
    case LONGBOARD_4BANKS:
      highestbank=3;
      startat=0;
      break;
    case SHORTBOARD_7BANKS:
      highestbank=7;
      startat=1;
      break;
    case SHORTBOARD_3BANKS:
      highestbank=3;
      startat=1; // because 0 is BASIC
      break;
    case C1541C_1541II:
      highestbank=1;
      startat=0;
      break;
  }

  if (rom>highestbank)
    rom = startat;

  flashcounter = rom*2;
  if (mode==LONGBOARD_8BANKS||mode==LONGBOARD_4BANKS) {
    flashcounter = (rom+1)*2;
  }
}

void load_setup() {
  mode = EEPROM.read(EEPROM_ADDRESS_MODE);
  if (mode>=MAX_MODES) mode=0;
  rom = EEPROM.read(0);
  rom = rom&0x07;
}

void save_setup() {
  EEPROM.write(EEPROM_ADDRESS_MODE, mode);
  delay(5);
}

void set_blinky_pattern() {
  if      ( mode==LONGBOARD_4BANKS )  { flashpattern=0x9C00; }
  else if ( mode==LONGBOARD_8BANKS )  { flashpattern=0xE700; }
  else if ( mode==SHORTBOARD_3BANKS ) { flashpattern=0x9000; }
  else if ( mode==SHORTBOARD_7BANKS ) { flashpattern=0xE400; }
  else if ( mode==C1541C_1541II )     { flashpattern=0xF7FF; }
  else { flashpattern=0x1000; }
}

void setup() {
  //sei();

  pinMode(RED, OUTPUT);
  pinMode(A13, OUTPUT);
  pinMode(A14, OUTPUT);
  pinMode(RESTORE, INPUT_PULLUP);
  pinMode(INTRST, INPUT);
  digitalWrite(RED, LOW);
  digitalWrite(A13, LOW);
  digitalWrite(A14, LOW);
                                                                                                                                                                                                                                                                                                                                                                                digitalWrite(INTRST, HIGH);

  pinMode(EXROM, INPUT);
  digitalWrite(EXROM, HIGH);

  //ss.attachInterrupt( handleRxChar );
  ss.begin( 19200 );

// poweron indicate EXROM availability
//  if(exrom_available)
//    flash_led(A13,2,50);
//  else
//    flash_led(A13,1,50);

  load_setup();

  counter=0;
}

void loop() {
  restore = digitalRead(RESTORE);
  switch (state)
  {
    case STATE_INIT:
    if (restore==0) { 
      counter++;
      if(counter>50*2) {
        counter=0;
        next_state = STATE_SETUP;
        set_blinky_pattern();
        digitalWrite(RED, HIGH);
        inhibit=1;
      }
    } else {
      next_state = STATE_IDLE;
      counter=0;
    }
    break;

    case STATE_SETUP:
      if (restore==0) counter++;
      else counter=0;
      if(counter++>50*2) {
        counter=0;
        save_setup();
        next_state = STATE_IDLE;
      }
      else if (last_press==0 && restore==1) {
        if(!inhibit) rotate_setup();
        inhibit=0;
        set_blinky_pattern();
      }
      if (flashpattern==0) set_blinky_pattern();
    break;

    case STATE_IDLE:
      if (restore==0) counter++;
      else { 
        counter=0;
        #ifdef USE_SLEEPMODE
        if (flashcounter==0) system_sleep();
        #endif
      }
      if (counter>PRESSTIME*2) {
        next_state = STATE_STILLHOLDING;
        counter=0;
      }
      break;

    case STATE_STILLHOLDING:
      if (restore==0) {
        if(flashcounter==0) flashcounter = 2;
        counter++;
        if (counter>HOLDTIME*2) {
          next_state = STATE_EXROMRESET;
          counter=0;
        }
      } else {
        next_state = STATE_MENU;
        counter=0;
        last_press=0;
      }
      break;

     case STATE_MENU:
      if(counter++>MENUTIMEOUT*2) {
        counter=0;
        next_state = STATE_RESET;
      }
      else if (last_press==1 && restore==0) {
        rotate_rom();

#ifndef REDONLY
        flashcounter=0;
#endif
 
        set_ledcolor(rom);
      }
      if (restore==0) counter=0;
      break;

    case STATE_RESET:
      flashcounter=0;
      set_ledcolor(rom);
      next_state = STATE_IDLE;
      ss.ignore();
      ss.write(0xde);
      ss.write(rom);
      pinMode(INTRST, OUTPUT);
      digitalWrite(INTRST, LOW);
      delay(300);
      pinMode(INTRST, INPUT);
      ss.listen();
      EEPROM.write(0, rom&0x07);
      delay(5);
      break;

    case STATE_EXROMRESET:
      flashcounter=0;
      set_ledcolor(rom);
      next_state = STATE_IDLE;
      digitalWrite(INTRST, LOW);
      pinMode(INTRST, OUTPUT);
      delay(100);

      pinMode(EXROM, OUTPUT);
      digitalWrite(EXROM, LOW);
      delay(300);
      
      pinMode(INTRST, INPUT);
      digitalWrite(INTRST, HIGH);
      delay(100);

      pinMode(EXROM, INPUT);
      digitalWrite(EXROM, HIGH);
      EEPROM.write(0, rom&0x07);
      delay(300);

    default:
      break;

  }
  last_press = restore;
  state = next_state;

  while (ss.available()) {
    uint8_t data = ss.read();
    if (data==0xde) {
      delay(1);
      if (ss.available()) {
        rom=(ss.read());
        flashcounter=0;
        set_ledcolor(rom);
      }
    }
  }

  // flash led ?
  if (flashcounter>0) {
    digitalWrite(RED, (flashcounter&0x01)==1);
    flashcounter--;
  } else if (flashpattern>0) {
    if(--flashdivision<=0) {
      digitalWrite(RED, (flashpattern&0x01)==1);
      digitalWrite(A13, (flashpattern&0x01)==1);
      digitalWrite(A14, (flashpattern&0x01)==1);
      flashpattern = flashpattern >> 1;
      flashdivision=2;
    }
  } else 
    set_ledcolor(rom);
  delay(50);
}

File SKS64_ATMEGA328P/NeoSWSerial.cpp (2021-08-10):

//
// NeoSWSerial
// Copyright (C) 2015-2017, SlashDevin
//
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
//     <http://www.gnu.org/licenses/>.
//
// Methods
// -------
//
// begin(baudRate) - initialization, optionally set baudrate, and then enable RX
// listen() - enables RX interrupts, allowing data to enter the RX buffer
// ignore() - disables RX interrupts
// setBaudRate(baudRate) - selects the baud rate (9600, 19200, 31250, 38400)
//                             - any other value is ignored
// available() - returns the number of characters in the RX buffer
// read() - returns a single character from the buffer
// write(s) - transmits a string
//
// print() is supported
//=============================================================================

#include "NeoSWSerial.h"

// Default baud rate is 9600
static const uint8_t TICKS_PER_BIT_9600 = (uint8_t) 26;
                              // 9600 baud bit width in units of 4us
static const uint8_t TICKS_PER_BIT_31250 = 8;
                              // 31250 baud bit width in units of 4us

static const uint8_t BITS_PER_TICK_31250_Q10 = 128;
                     // 31250 bps * 0.000004 s * 2^10 "multiplier"
static const uint8_t BITS_PER_TICK_38400_Q10 = 157;
                     // 1s/(38400 bits) * (1 tick)/(4 us) * 2^10  "multiplier"

#if F_CPU == 16000000L
  #define TCNTX TCNT0
  #define PCI_FLAG_REGISTER PCIFR
#elif F_CPU == 8000000L
  #if defined(__AVR_ATtiny25__) | \
      defined(__AVR_ATtiny45__) | \
      defined(__AVR_ATtiny85__) 
    #define TCNTX TCNT1
    #define PCI_FLAG_REGISTER GIFR
  #else
    #define TCNTX TCNT2
    #define PCI_FLAG_REGISTER PCIFR
  #endif
#endif

static NeoSWSerial *listener = (NeoSWSerial *) NULL;

static uint8_t txBitWidth;
static uint8_t rxWindowWidth;
static uint8_t bitsPerTick_Q10; // multiplier!

static const uint8_t WAITING_FOR_START_BIT = 0xFF;
static uint8_t rxState;  // 0: got start bit; >0: bits rcvd
static uint8_t prev_t0;  // previous RX transition: timer0 time stamp (4us)
static uint8_t rxMask;   // bit mask for building received character
static uint8_t rxValue;  // character being built

static const uint8_t RX_BUFFER_SIZE = 64;  // power of 2 for optimal speed
static uint8_t rxBuffer[RX_BUFFER_SIZE];
static uint8_t rxHead;   // buffer pointer input
static uint8_t rxTail;   // buffer pointer output

static          uint8_t rxBitMask, txBitMask; // port bit masks
static volatile uint8_t *txPort;  // port register

//#define DEBUG_NEOSWSERIAL
#ifdef DEBUG_NEOSWSERIAL

  uint8_t bitTransitionTimes[16];
  uint8_t bitTransitions;
  static const uint8_t MAX_DIFF_RX_BITS = 8;
  struct rbd_t { uint8_t loop_bits; uint8_t mul_bits; uint16_t prod; };
  rbd_t diffRXbits[MAX_DIFF_RX_BITS];
  uint8_t diffRXbitsCount;

  uint16_t availCompletions;
  uint16_t rxStartCompletions;
  uint8_t rxStartCompletionBits[128];
  uint16_t checkRxCompletions;
  uint16_t polledPCI;
  uint16_t polledPCICompletions;
  uint16_t stopBitCompletions;

  #define DBG_NSS_COUNT(v) { v++; }
  #define DBG_NSS_COUNT_RESET(v) { v = 0; }
  #define DBG_NSS_ARRAY(a,i,v) \
    { if (i < sizeof(a)/sizeof(a[0])) \
      a[ i++ ] = v; }

#else

  #define DBG_NSS_COUNT(v)
  #define DBG_NSS_COUNT_RESET(v)
  #define DBG_NSS_ARRAY(a,i,v)

#endif

static uint16_t mul8x8to16(uint8_t x, uint8_t y)
{return x*y;}

//..........................................

static uint16_t bitTimes( uint8_t dt )
{
  return mul8x8to16( dt + rxWindowWidth, bitsPerTick_Q10 ) >> 10;

} // bitTimes

//----------------------------------------------------------------------------

void NeoSWSerial::begin(uint16_t baudRate)
{
  setBaudRate( baudRate );
  listen();
}

//----------------------------------------------------------------------------

void NeoSWSerial::listen()
{
  
  if (listener)
    listener->ignore();

  pinMode(rxPin, INPUT);
  rxBitMask = digitalPinToBitMask( rxPin );
  rxPort    = portInputRegister( digitalPinToPort( rxPin ) );

  txBitMask = digitalPinToBitMask( txPin );
  txPort    = portOutputRegister( digitalPinToPort( txPin ) );
  if (txPort)
    *txPort  |= txBitMask;   // high = idle
  if (rxPin!=txPin)
    pinMode(txPin, OUTPUT);

  if (F_CPU == 8000000L) {
    // Have to use timer 2 for an 8 MHz system.
    #if defined(__AVR_ATtiny25__) | \
        defined(__AVR_ATtiny45__) | \
        defined(__AVR_ATtiny85__) 
      TCCR1  = 0x06;  // divide by 32
    #else
      TCCR2A = 0x00;
      TCCR2B = 0x03;  // divide by 32
    #endif
  }

  volatile uint8_t *pcmsk = digitalPinToPCMSK(rxPin);
  if (pcmsk) {
    rxState  = WAITING_FOR_START_BIT;
    rxHead   = rxTail = 0;    // no characters in buffer
    flush();

    // Set up timings based on baud rate
    
    switch (_baudRate) {
      case 9600:
        txBitWidth      = TICKS_PER_BIT_9600          ;
        bitsPerTick_Q10 = BITS_PER_TICK_38400_Q10 >> 2;
        rxWindowWidth   = 10;
        break;
      case 31250:
        if (F_CPU > 12000000L) {
          txBitWidth = TICKS_PER_BIT_31250;
          bitsPerTick_Q10 = BITS_PER_TICK_31250_Q10;
          rxWindowWidth = 5;
          break;
        } // else use 19200
      case 38400:
        if (F_CPU > 12000000L) {
          txBitWidth      = TICKS_PER_BIT_9600    >> 2;
          bitsPerTick_Q10 = BITS_PER_TICK_38400_Q10   ;
          rxWindowWidth   = 4;
          break;
        } // else use 19200
      case 19200:
        txBitWidth      = TICKS_PER_BIT_9600      >> 1;
        bitsPerTick_Q10 = BITS_PER_TICK_38400_Q10 >> 1;
        rxWindowWidth   = 6;
        break;
    }

    // Enable the pin change interrupts

    uint8_t prevSREG = SREG;
    cli();
    {
      *pcmsk                    |= _BV(digitalPinToPCMSKbit(rxPin));
      *digitalPinToPCICR(rxPin) |= _BV(digitalPinToPCICRbit(rxPin));
      listener = this;
    }
    SREG = prevSREG;
  }

} // listen

//----------------------------------------------------------------------------

void NeoSWSerial::ignore()
{
  if (listener) {
    volatile uint8_t *pcmsk = digitalPinToPCMSK(rxPin);

    uint8_t prevSREG = SREG;
    cli();
    {
      listener = (NeoSWSerial *) NULL;
      if (pcmsk) {
        *digitalPinToPCICR(rxPin) &= ~_BV(digitalPinToPCICRbit(rxPin));
        *pcmsk &= ~_BV(digitalPinToPCMSKbit(rxPin));
      }
    }
    SREG = prevSREG;
  }

} // ignore

//----------------------------------------------------------------------------

void NeoSWSerial::setBaudRate(uint16_t baudRate)
{
  if ((
        ( baudRate ==  9600) ||
        ( baudRate == 19200) ||
        ((baudRate == 31250) && (F_CPU == 16000000L)) ||
        ((baudRate == 38400) && (F_CPU == 16000000L))
       )
           &&
      (_baudRate != baudRate)) {

    _baudRate = baudRate;

    if (this == listener)
      listen();
  }
} // setBaudRate

//----------------------------------------------------------------------------
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

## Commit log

2016-08-20 first commit
    my first commit
    [c64switchless.brd, c64switchless.sch, c64switchless_555.brd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]
2016-08-20 PDF file added
    Note that this 555 based design is not completed.
    [c64switchless_555.sch]
2016-08-20 Optional MCU
    The MCU is optional in the 555 design. I added the footprint because
    space was available. Not finished.
    [c64switchless_555.sch]
2016-08-22 555 based: updated R2,R3. Added revision.
    [c64switchless_555.brd, c64switchless_555.sch]
2016-08-22 Revision + silkscreen text
    [c64switchless.brd, c64switchless.sch]
2016-09-08 swapped LED and RESTORE on GP2 and GP3
    GP3 is the fekken input only pin
    [c64switchless.brd, c64switchless.sch]
2016-09-10 Sch+Layout changed to match RGB LEDs pinout
    See readme.txt
    [c64switchless.brd, c64switchless.sch]
2016-09-10 Rev 1.11 Silkscreen, RGB LED
    [c64switchless.brd]
2016-09-10 silkscreen was on wrong layer - move 555 version
    [c64switchless_555.brd, c64switchless_555.sch]
2016-09-10 Bill of materials
2016-09-16 removed kernal=0 and using switch-case block
2016-09-17 updated with license
    [c64switchless.brd, c64switchless.sch]
2016-09-18 hole sizes
    [c64switchless.brd, c64switchless.sch]
2016-09-19 mikroC config file
    [C64MultiKernel.cfg]
2016-09-28 Rev 1.13
    Moved IC2 to clear space for the socket in the C64.
    [c64switchless.brd, c64switchless.sch]
2017-11-10 documentation still at a very early stage
2017-11-19 Documented the LED assembly and overview.
    PDF is old.
2019-05-16 Added assembly instructions in the manual
2019-05-16 resistor values
    [c64switchless.brd, c64switchless.sch]
2019-06-22 schematics and layout in user guide
2019-07-15 User Guide
    not finished
    [C64-Switchless-Quad-Kernal-Switcher.kicad_pcb]
2019-07-17 firmware updates: use eprom, exromreset, opencollector
    opencollector-ish means set reset and exrom as input when inactive.
    [C64-Switchless-Quad-Kernal-Switcher.sch, bom_v1_20.csv]
2019-07-18 Preparing for shortboard version
    [C64-Switchless-Quad-Kernal-Switcher-B_Cu.gbr, C64-Switchless-Quad-Kernal-Switcher-B_Mask.gbr, C64-Switchless-Quad-Kernal-Switcher-B_Paste.gbr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]
2019-07-18 User Guide. Soldering instructions
2019-07-18 Update SKS64_SKETCH.ino
    still a bit buggy
    [SKS64_SKETCH.ino]
2019-07-19 Firmware: Setup menu, motherboard and no. banks stored on eprom, small bugfixes
    Only need one firmware for all the possible usage types
    longboard, shortboard, 4 banks, 8 banks.
    [SKS64_SKETCH.ino]
2019-07-20 shortboard version not tested
    [C64-Switchless-Quad-Kernal-Switcher.kicad_pcb, C64-Switchless-Quad-Kernal-Switcher.sch, bom_v1_20.csv]
2019-07-21 Readme, 250469 wiring, user guide
2019-07-23 longboard pcb version, 8 bank support
    [C64-Switchless-Quad-Kernal-Switcher-B_Cu.gbr, C64-Switchless-Quad-Kernal-Switcher-B_Mask.gbr, C64-Switchless-Quad-Kernal-Switcher-B_Paste.gbr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]
2019-07-24 shortboard version schematics added to user guide
    [C64-Switchless-Quad-Kernal-Switcher.kicad_pcb, C64-Switchless-Quad-Kernal-Switcher.sch]
2019-07-24 RED turned on after EXROM reset (flashcounter not zero)
    [SKS64_SKETCH.ino]
2019-08-12 Updated BOM shortboard in User Guide. Added mouserproject link
    [bom.csv, bom_v1_20.csv]
2021-01-06 Set EXROM to input on startup instead of output - otherwise EXROM is held high until first reboot
    [SKS64_SKETCH.ino]
2021-05-03 Removed led flashing delay at start of program. The flashing caused C64C to not warm start.
2021-05-03 Updated User Guide. Make it clearer to select fusebits.
2021-07-27 1.4 fixed: A15 always 0 at cold boot in 8 banks longboard mode
    [SKS64_SKETCH.ino]
2021-08-10 1541C support in firmware and SKS64 shortboard pcb version
    [C64-Switchless-Quad-Kernal-Switcher.kicad_pcb, C64-Switchless-Quad-Kernal-Switcher.sch]
2021-08-10 firmware: removed startup delay (1s) causing startup issues
    [SKS64_SKETCH.ino]
2021-08-10 Documentation update includes 1541
    [bom.csv]
2022-04-03 The arduino code ported to atmega328p (arduino uno)

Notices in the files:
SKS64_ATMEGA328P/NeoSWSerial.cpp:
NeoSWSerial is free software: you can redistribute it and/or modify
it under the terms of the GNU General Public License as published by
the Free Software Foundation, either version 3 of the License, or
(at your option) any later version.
